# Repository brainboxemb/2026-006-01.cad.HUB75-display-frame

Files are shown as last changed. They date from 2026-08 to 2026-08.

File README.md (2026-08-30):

# HUB75 Display Frame

> The model and documentation were developed with the assistance of ChatGPT.

This repository contains the OpenSCAD development of a frame for five HUB75 LED matrix panels.

The design uses a modular OpenSCAD structure with reusable physical components, project-specific derived components and assemblies. Individual parts can be opened, rendered and tuned independently, while the complete construction can be viewed from `main.scad`.

> **Project status:** Concept development  
> V1.0 explored a frame based on 20 × 20 mm aluminium extrusion and is mainly retained as a reference concept. V1.1 explored a modular 3D-printed frame combined with two continuous aluminium tubes. Active development has moved to V1.2, which deliberately reduces the printed structure to direct panel-to-panel couplers so the mechanical strength can be tested before adding more complexity. The V1.2 couplers now use four profile modes: `large`, `medium`, `small` and `custom`; the three named presets are fixed, while `custom` activates individually editable dimensions.

## V1.0

### Inspiration

The aluminium-frame approach in V1.0 was inspired by the Instructables project [**Simple Extruded Aluminum Frame for LED Panels**](https://www.instructables.com/Simple-Extruded-Aluminum-Frame-for-LED-Panels/), created by **NotLikeALeafOnTheWind**.

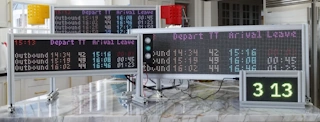
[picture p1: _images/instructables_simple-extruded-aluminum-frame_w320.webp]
Simple Extruded Aluminum Frame for LED Panels - Instructables reference (https://www.instructables.com/Simple-Extruded-Aluminum-Frame-for-LED-Panels/)


*Source: [Instructables / NotLikeALeafOnTheWind — Simple Extruded Aluminum Frame for LED Panels](https://www.instructables.com/Simple-Extruded-Aluminum-Frame-for-LED-Panels/). The image is included as a visual reference to the original project. Copyright remains with the original creator.*

### Concept

V1.0 explores an aluminium-extrusion-based structure for supporting the HUB75 panels and the components mounted directly to that structure.

The concept includes:

- a 20 × 20 mm aluminium extrusion frame;
- five HUB75 LED matrix panels;
- panel mounting brackets;
- TS35 DIN rails positioned around the panel seams;
- cable clips and ribbon-cable routing;
- frame-mounted fasteners;
- optional ESP32 mounting;
- optional power-supply mounting.

V1.0 is a concept drawing and is primarily retained as a reference for this construction approach.

The OpenSCAD model is stored in:

```text
v1.0/cad/
```

### Renders

Reference renders generated from the V1.0 OpenSCAD model are stored in:

```text
v1.0/out/png/
```

#### Front view

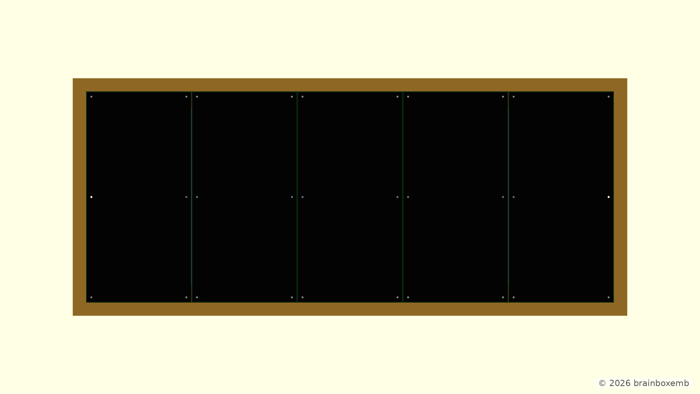
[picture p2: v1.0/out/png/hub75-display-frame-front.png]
HUB75 display frame V1.0 - front view


#### Front angled view

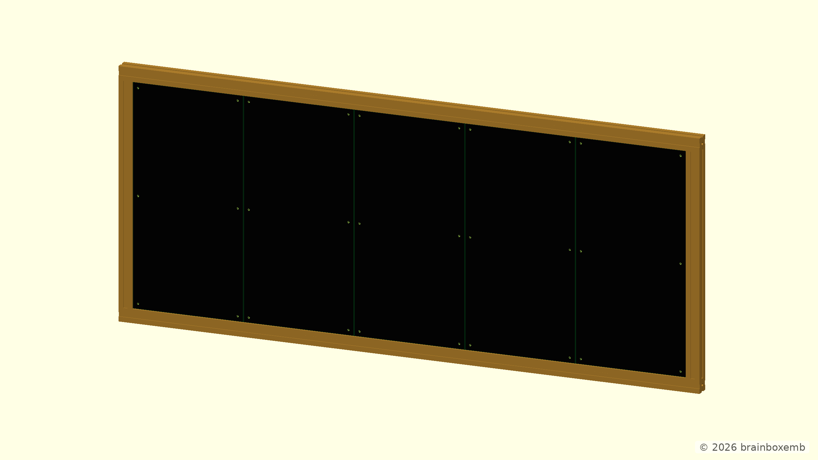
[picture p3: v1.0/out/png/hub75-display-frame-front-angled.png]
HUB75 display frame V1.0 - front angled view


#### Rear view

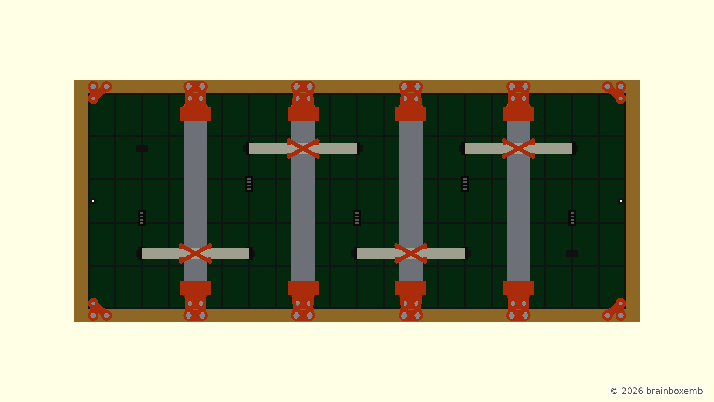
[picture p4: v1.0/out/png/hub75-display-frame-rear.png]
HUB75 display frame V1.0 - rear view


#### Rear angled view

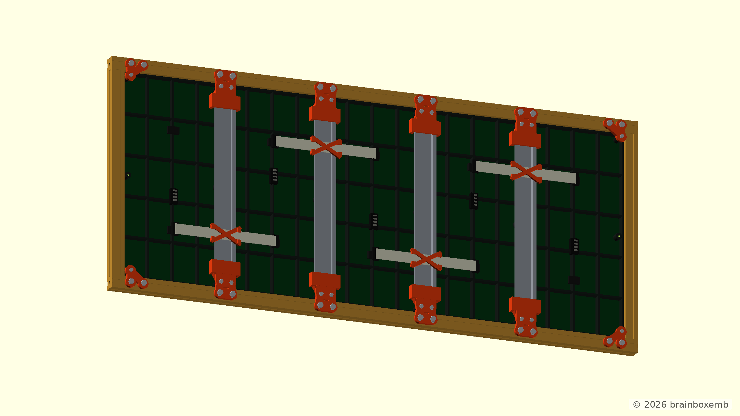
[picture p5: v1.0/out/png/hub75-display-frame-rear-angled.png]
HUB75 display frame V1.0 - rear angled view


#### Exploded rear view

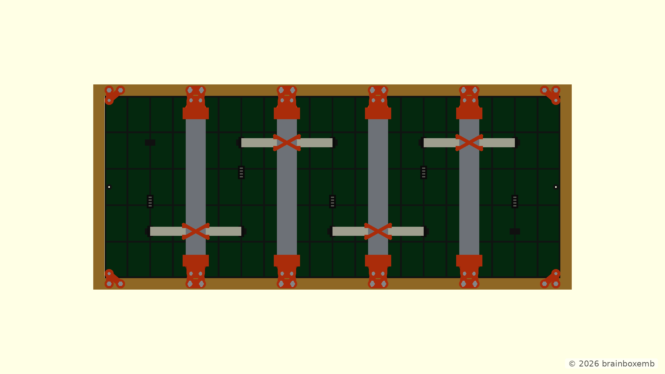
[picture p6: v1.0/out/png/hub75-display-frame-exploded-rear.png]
HUB75 display frame V1.0 - exploded rear view


#### Exploded rear angled view

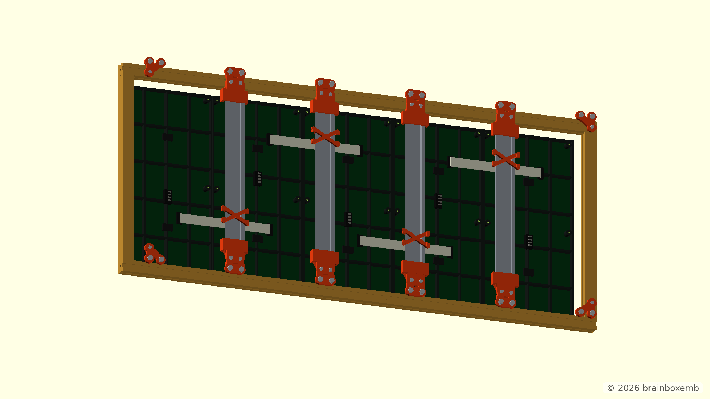
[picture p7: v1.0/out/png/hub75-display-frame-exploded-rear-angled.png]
HUB75 display frame V1.0 - exploded rear angled view


### CAD structure

The V1.0 OpenSCAD model is divided into configuration, individual components and assemblies. Fixed render definitions are included so documentation images can be reproduced locally or by the shared GitHub Actions renderer.

```text
v1.0/cad/
├── main.scad
├── config/
│   └── project_config.scad
├── components/
│   ├── ...
│   └── _lib/
│       └── fasteners.scad
├── assemblies/
│   ├── display_assembly.scad
│   ├── frame_assembly.scad
│   ├── panels_assembly.scad
│   ├── hardware_assembly.scad
│   ├── frame_system_assembly.scad
│   └── ...
└── renders/
    ├── front.scad
    ├── front_angled.scad
    ├── rear.scad
    ├── rear_angled.scad
    ├── exploded_rear.scad
    └── exploded_rear_angled.scad
```

Open `v1.0/cad/main.scad` to view and configure the complete model.

## V1.1

### Inspiration

The modular frame approach explored in V1.1 was partly inspired by a **modular MFT router jig**. Its use of repeatable 3D-printed sections that combine into a larger structure helped shape the idea of building the HUB75 support frame from a regular grid of printed modules.

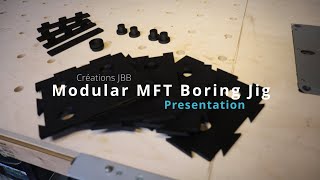
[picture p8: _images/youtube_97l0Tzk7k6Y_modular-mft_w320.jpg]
Modular MFT concept - YouTube reference (https://www.youtube.com/watch?v=97l0Tzk7k6Y)


*Source: [YouTube — Modular MFT reference](https://www.youtube.com/watch?v=97l0Tzk7k6Y). The image is included as a visual reference to the original video. Copyright remains with the original creator.*

The MFT concept was used as inspiration for the **modular construction principle and overall module shape**. V1.1 adapts that idea to the mechanical requirements and mounting pattern of the HUB75 display panels.

### Concept

V1.1 takes a different approach to the structural frame.

Instead of using 20 × 20 mm aluminium extrusion as the main structure, the frame is built from modular **160 × 160 mm 3D-printed sections**. The module size follows the nominal 160 mm dimension of the HUB75 panels and creates a regular 5 × 2 structural grid behind the five displays.

The current concept includes:

- ten 160 × 160 mm 3D-printed frame modules;
- large central openings to reduce material usage and keep the rear of the panels accessible;
- interlocking edges that position neighbouring frame modules;
- alternating module colours in the OpenSCAD model to make the modular construction easier to inspect;
- mounting features that use the existing HUB75 panel screw locations;
- dedicated seam joiners connecting neighbouring panels and frame sections;
- two continuous Ø10 × 1 mm aluminium tubes, each 800 mm long;
- integrated snap clamps connecting the upper and lower frame modules to these tubes.

The aluminium tubes provide a continuous structural reference across the full width of the display and are intended to improve alignment and stiffness.

Their position also leaves open the possibility of using the tubes as a mounting interface for additional parts on the front side, such as a future display surround or bezel.

V1.1 is retained as the more elaborate modular printed-frame concept. V1.2 intentionally simplifies this approach before further refinement.

The OpenSCAD model is stored in:

```text
v1.1/cad/
```

### Renders

Reference renders generated from the current V1.1 OpenSCAD model are stored in:

```text
v1.1/out/png/
```

#### Front view

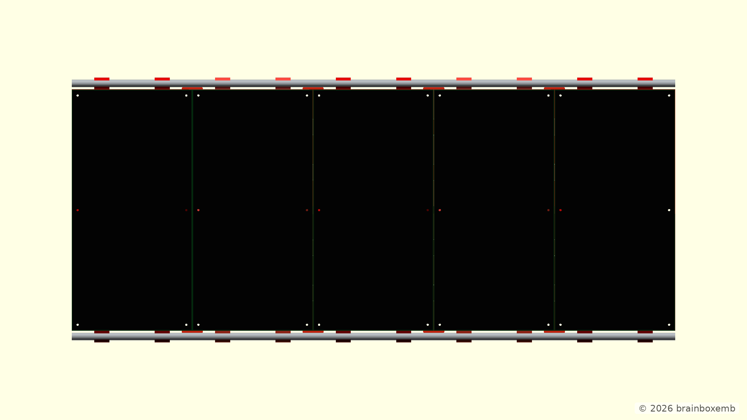
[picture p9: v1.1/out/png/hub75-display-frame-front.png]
HUB75 display frame V1.1 - front view


#### Front angled view

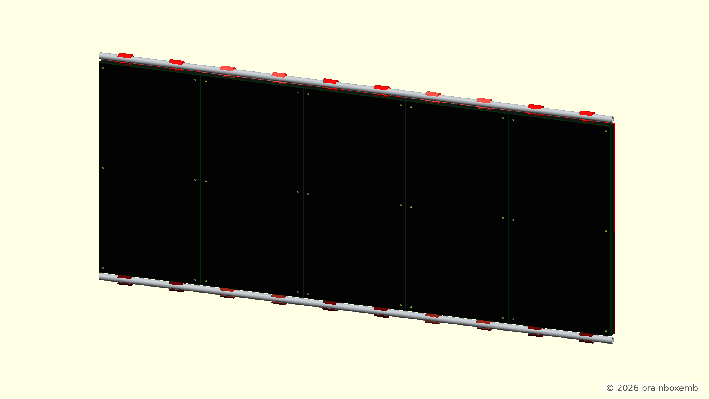
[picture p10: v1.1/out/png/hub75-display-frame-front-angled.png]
HUB75 display frame V1.1 - front angled view


#### Rear view

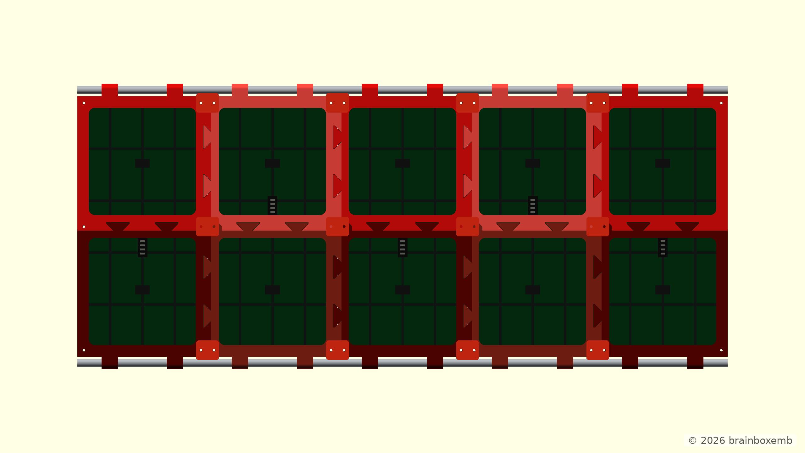
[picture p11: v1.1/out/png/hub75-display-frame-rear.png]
HUB75 display frame V1.1 - rear view


#### Rear angled view

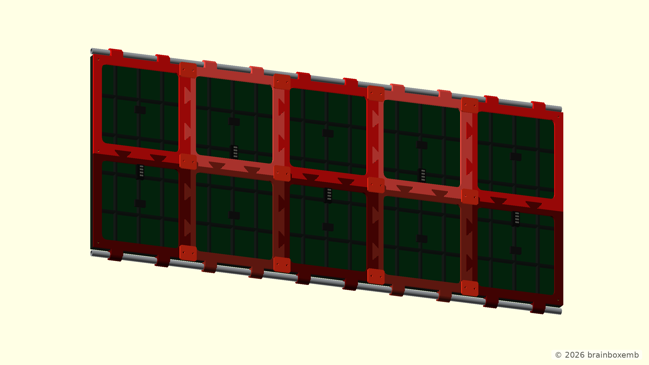
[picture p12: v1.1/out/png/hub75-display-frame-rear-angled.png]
HUB75 display frame V1.1 - rear angled view


#### Exploded rear view

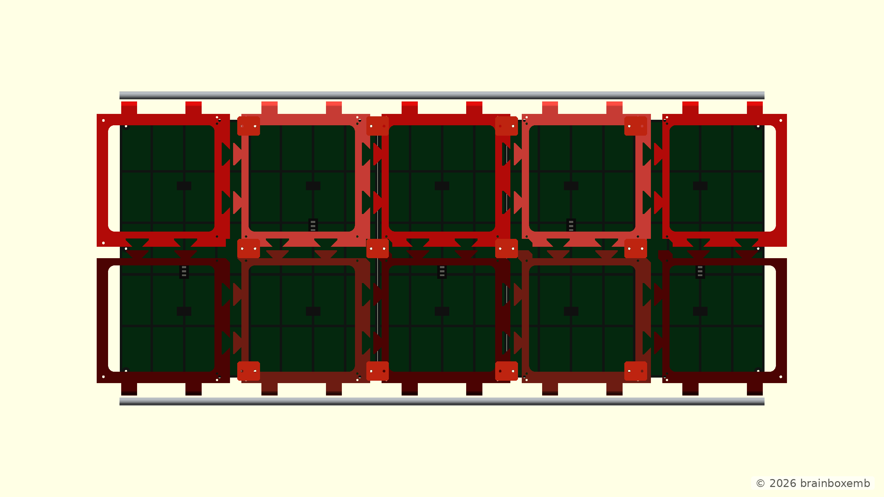
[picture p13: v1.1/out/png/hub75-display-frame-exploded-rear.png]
HUB75 display frame V1.1 - exploded rear view


#### Exploded rear angled view

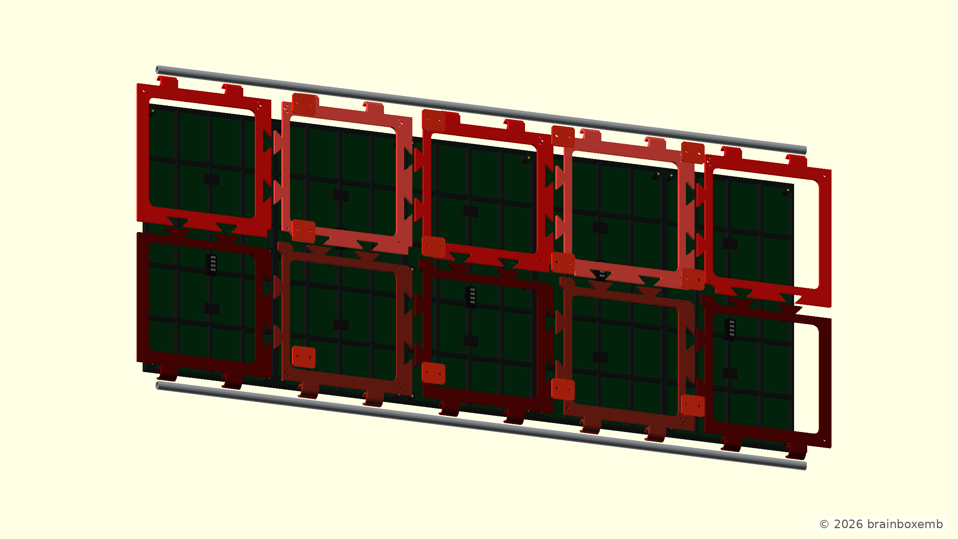
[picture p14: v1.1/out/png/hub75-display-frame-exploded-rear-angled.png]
HUB75 display frame V1.1 - exploded rear angled view


### CAD structure

V1.1 continues to use the modular OpenSCAD structure introduced for the project.

```text
v1.1/cad/
├── main.scad
├── config/
│   └── project_config.scad
├── components/
│   ├── hub75_panel.scad
│   ├── frame_module.scad
│   ├── panel_seam_joiner.scad
│   └── ...
├── assemblies/
│   ├── panels_assembly.scad
│   ├── frame_modules_assembly.scad
│   ├── seam_joiners_assembly.scad
│   ├── display_assembly.scad
│   └── ...
└── renders/
    ├── front.scad
    ├── front_angled.scad
    ├── rear.scad
    ├── rear_angled.scad
    ├── exploded_rear.scad
    └── exploded_rear_angled.scad
```

Open `v1.1/cad/main.scad` to view the complete concept.

## V1.2

V1.2 coupler placement is based on the exact 160 × 320 mm nominal panel grid. Local seam locators use the larger gap at the tapered rear mounting plane, with 0.25 mm print clearance per side; see `v1.2/doc/grid-and-fit.md`.

### Concept

V1.2 is a deliberately simpler continuation of V1.1.

Instead of building a complete 160 × 160 mm printed frame grid first, V1.2 connects the HUB75 panels directly at their existing screw positions. The purpose of this version is to manufacture and test the simplest useful structure and determine how much stiffness the direct panel connections and aluminium tubes already provide.

The current V1.2 concept includes:

- five HUB75 panels in the same nominal 800 × 320 mm arrangement;
- no 160 × 160 mm printed frame modules;
- no puzzle or dovetail interlocks;
- four `middle_panel_coupler` parts at the internal panel seams;
- upper and lower `horizontal_edge_panel_coupler` parts at each internal seam;
- separate mirrored `corner_edge_panel_coupler` variants at the four outside corners;
- two continuous Ø10 × 1 mm aluminium tubes;
- dedicated fit-section views for checking the coupler-to-panel interfaces.

The printed couplers follow the actual rear-panel rib geometry and use the existing screw locations, locator features and reinforcement-bushing geometry as alignment references. The edge and corner families are dimensioned from the nominal 160 × 320 mm panel boundary while their physical fit geometry remains tied to the real panel rails, holes and bosses. This keeps the parts visually and mechanically consistent without moving the real fit features.

The nominal placement grid is authoritative: the original panel is **320 × 160 mm**, and in this portrait assembly each cell is therefore **160 mm in X × 320 mm in Z**. The measured physical panel is 159.70 × 319.71 mm and is centred inside that cell. Internal coupler centres sit exactly on the nominal grid boundaries, while the physical undersize appears only as a small panel-to-panel gap. Panel-fit guides use a fixed **0.25 mm clearance per mating side**, independent of the small/medium/large coupler profile. The seam locator does not use the 0.30 mm front/body gap: it engages at the tapered rear mounting plane, where the usable seam is wider. With the STEP-derived rear inset and 0.25 mm print clearance per mating side, the current locator is about 2.30 mm wide and remains centred exactly on the nominal grid seam. The same mounting-plane rule is now used for the guide keep-outs themselves: because the outer housing tapers inward while the bay openings remain vertical, the effective side/end rails at the rear face are smaller than the nominal 12.5/10.75 mm reference widths. Middle, horizontal-edge and corner guides therefore all use the same rear-plane rail dimensions before adding the fixed 0.25 mm clearance.

### Panel dimensional basis

For V1.2, the panel's mechanical dimensions and mounting pattern are modelled in `components/hub75_panel.scad`. This component is deliberately project-independent and is the authoritative source for the physical panel geometry.

Current principal dimensions are:

```text
Panel width       159.70 mm
Panel height      319.71 mm
Panel depth        14.50 mm
```

The panel component also owns the rear rib geometry, mounting-hole pattern, IDC connector geometry, locator pins and reinforcement-bushing dimensions. The reinforcement feature is modelled as a Ø14 mm internal boss that is flush with the rear mounting plane, with a Ø10 mm × 2.5 mm recess and a central Ø2.5 mm blind hole extending 10 mm from the bottom of that recess.

### Aluminium tube layout

V1.2 now defines the aluminium-tube placement as an explicit **project-level relationship**, rather than deriving it indirectly from the clip geometry.

The current reference envelope is:

```text
Overall project envelope       840 × 360 mm
Tube centre-to-centre spacing  340 mm
Tube outer diameter             10 mm
Tube centre from panel rear      7 mm
```

The 840 × 360 mm project envelope is centred around **X = 0 / Z = 0**. The project assembly uses the **rear mounting plane of the HUB75 panels as Y = 0**. The two tube centres are positioned symmetrically at Z = ±170 mm, giving a 340 mm centre-to-centre distance. Their Y centre is **-7 mm**, i.e. 7 mm from the rear mounting plane toward the panel front.

`main.scad` also provides an optional `show_project_envelope` checkbox. When enabled, a wireframe 840 × 360 mm reference box is drawn around the assembly. Its Y-direction corner lines extend from the panel front face to the Y=0 rear mounting plane, making the panel depth and the project Y reference easy to inspect.

The Y position is defined from the **rear mounting plane of the HUB75 panel toward the front face**. With the rear plane at Y=0, the 14.5 mm panel front is at Y=-14.5 mm and the Ø10 mm tube centre is at Y=-7 mm. This leaves:

- 2.0 mm between the rear panel plane and the nearest tube surface;
- 2.5 mm between the opposite tube surface and the panel front face.

This relationship is stored in `config/project_config.scad` as:

```scad
display_envelope_width = 840.0;
display_envelope_height = 360.0;
tube_center_spacing = 340.0;
tube_center_from_panel_rear = 7.0;
```

The physical tube dimensions remain in `components/aluminium_tube.scad`.

### Configuration architecture

V1.2 deliberately separates **reusable physical components** from **project-derived printable parts**.

`components/` contains parts whose physical definition is independent of this specific five-panel assembly. Examples include:

- `hub75_panel.scad` — authoritative HUB75 panel geometry;
- `aluminium_tube.scad` — physical tube diameter and wall thickness;
- `tube_clip.scad` — reusable snap-clip geometry;
- `_lib/reference_grid.scad` — generic inspection helper.

`project_components/` contains printable parts whose geometry is deliberately derived from both reusable component dimensions and `project_config.scad`. The V1.2 couplers belong here because their clip positions, display-edge relationships and assembly clearances are specific to this project configuration. Shared coupler rules such as rail-following fit and profile dimensions are kept in `project_components/_lib/` so edge and corner variants do not duplicate those calculations. The material wall and guide height are selected through the project-wide coupler design profile.

This means it is expected and intentional that a file in `project_components/` can depend on project settings. A generic component under `components/` should not.

### Panel chain order

Panel order is defined **from the rear of the display**. By default, **panel 1 is the rear-left panel and its HUB75 input is at the top**. Every following panel is rotated 180 degrees so the data path snakes across the rear of the display.

The start side and the first input position are explicit project parameters:

```text
rear_chain_start_side = "left"
first_panel_input_side = "top"
```

### Bracket inspiration

The following Printables projects are useful references for refining the printed panel couplers and brackets.

#### Brackets for joining HUB75 LED panels

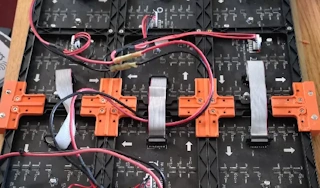
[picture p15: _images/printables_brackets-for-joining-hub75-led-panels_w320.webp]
Brackets for joining HUB75 LED panels (https://www.printables.com/model/1294572-brackets-for-joining-hub75-led-panels)


*Source: [Printables — Brackets for joining HUB75 LED panels](https://www.printables.com/model/1294572-brackets-for-joining-hub75-led-panels).*

#### HUB75 5mm Pitch 4 Panel Bracket

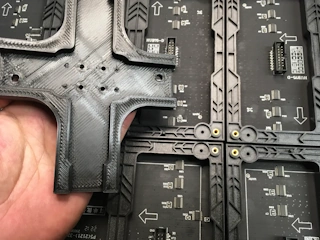
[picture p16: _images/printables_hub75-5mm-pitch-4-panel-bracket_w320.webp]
HUB75 5mm Pitch 4 Panel Bracket (https://www.printables.com/model/578204-hub75-5mm-pitch-4-panel-bracket)


*Source: [Printables — HUB75 5mm Pitch 4 Panel Bracket](https://www.printables.com/model/578204-hub75-5mm-pitch-4-panel-bracket).*

### Renders

Reference renders generated from the current V1.2 OpenSCAD model are stored in:

```text
v1.2/out/png/
```

#### Panel reference

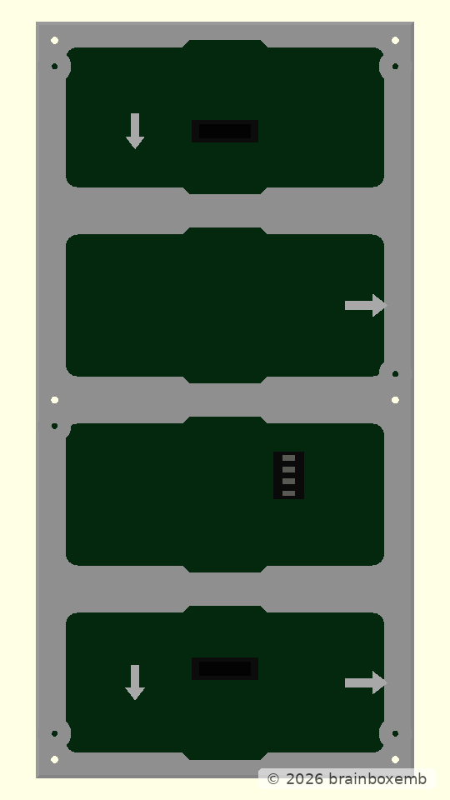
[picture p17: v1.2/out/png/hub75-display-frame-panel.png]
HUB75 panel V1.2 - rear reference


#### Panel reference — angled

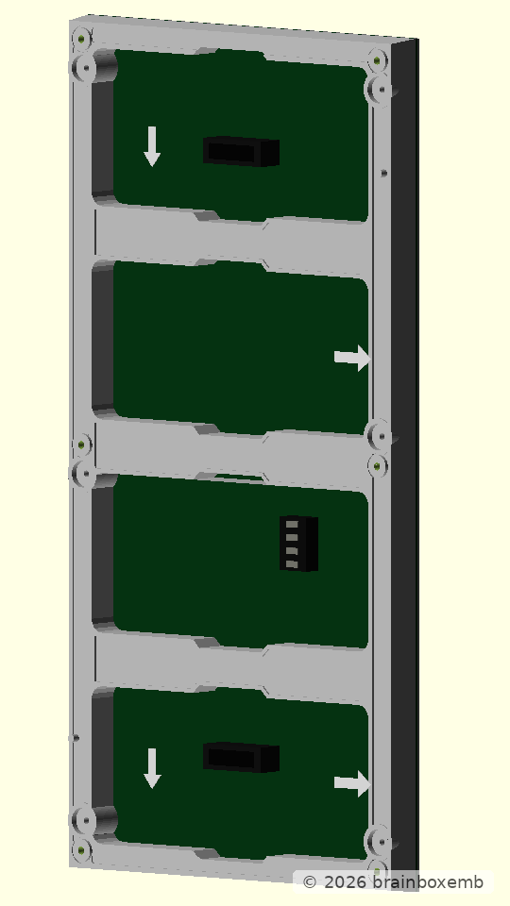
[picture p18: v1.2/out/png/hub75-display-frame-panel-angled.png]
HUB75 panel V1.2 - angled rear reference


#### Front view

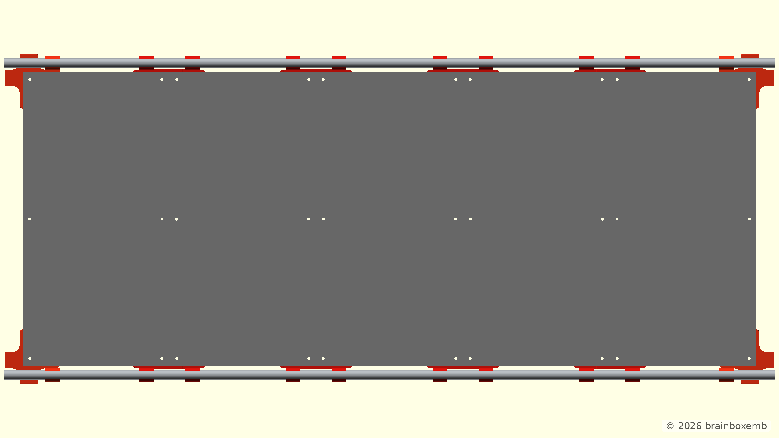
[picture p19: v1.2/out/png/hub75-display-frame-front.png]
HUB75 display frame V1.2 - front view


#### Front angled view

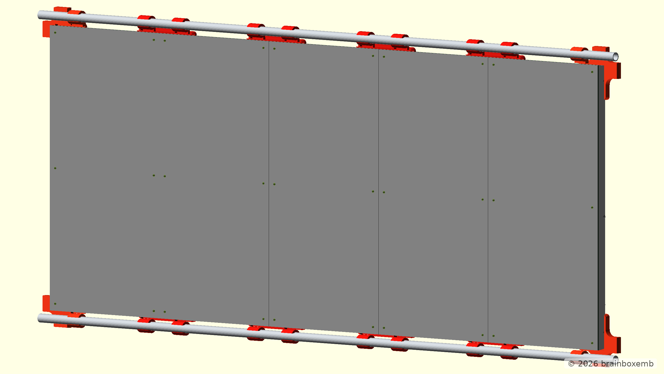
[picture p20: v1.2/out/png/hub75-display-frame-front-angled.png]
HUB75 display frame V1.2 - front angled view


#### Rear view

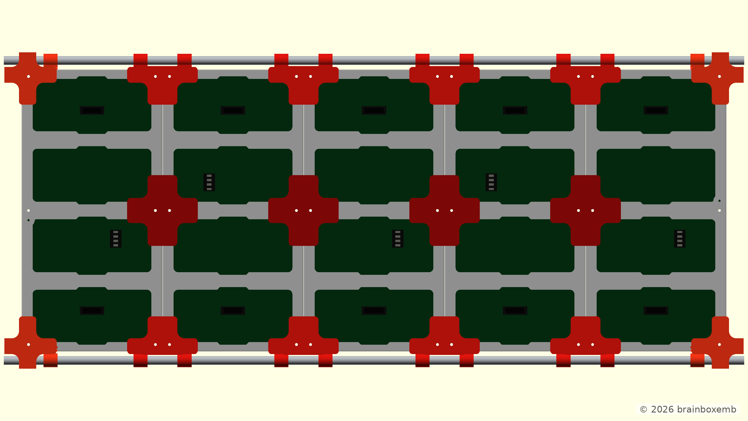
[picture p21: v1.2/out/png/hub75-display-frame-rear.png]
HUB75 display frame V1.2 - rear view


#### Rear angled view

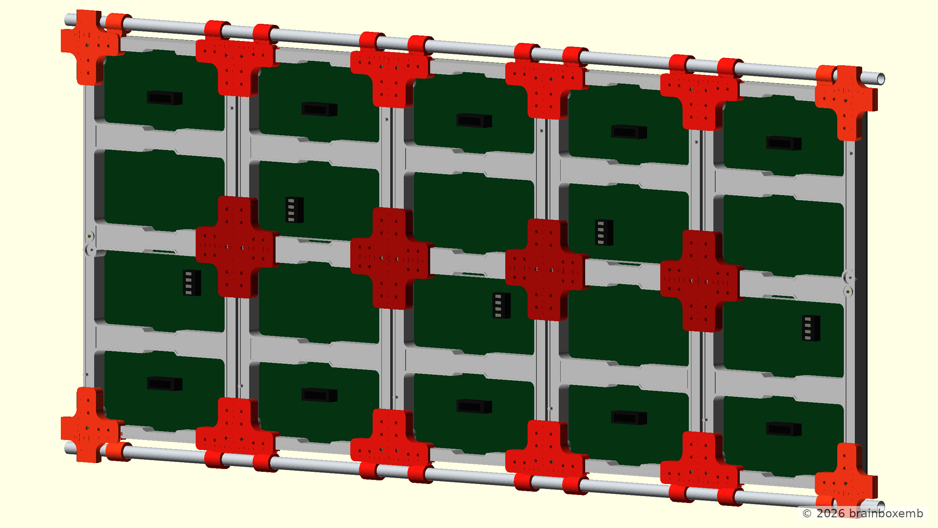
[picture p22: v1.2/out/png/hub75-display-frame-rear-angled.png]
HUB75 display frame V1.2 - rear angled view


#### Rear wiring / panel order

This view shows the HUB75 panel chain as seen from the rear. Panel 1 is the first module in the chain, with its input positioned at the top. The alternating panel orientation makes the intended IN/OUT routing across the five panels easier to verify.

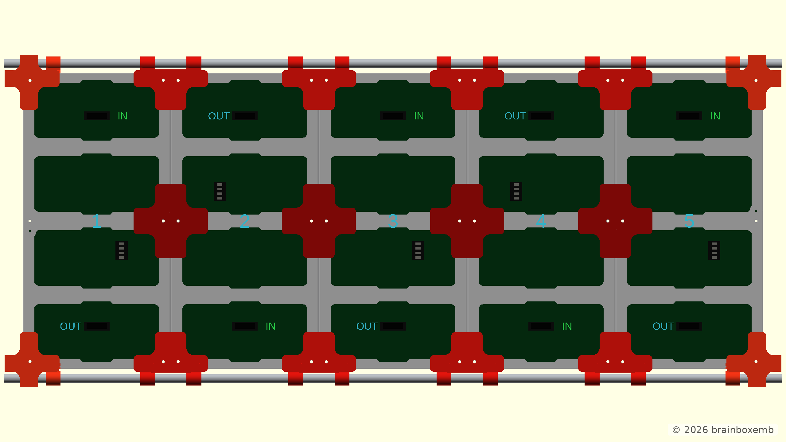
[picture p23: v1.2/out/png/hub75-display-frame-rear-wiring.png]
HUB75 display frame V1.2 - rear wiring and panel order


#### Rear fit section

This diagnostic render shows a section through the complete rear assembly, 5 mm into the panel structure. It is intended to make the fit between the printed couplers and the HUB75 rear ribs visible across all panel seams at once.

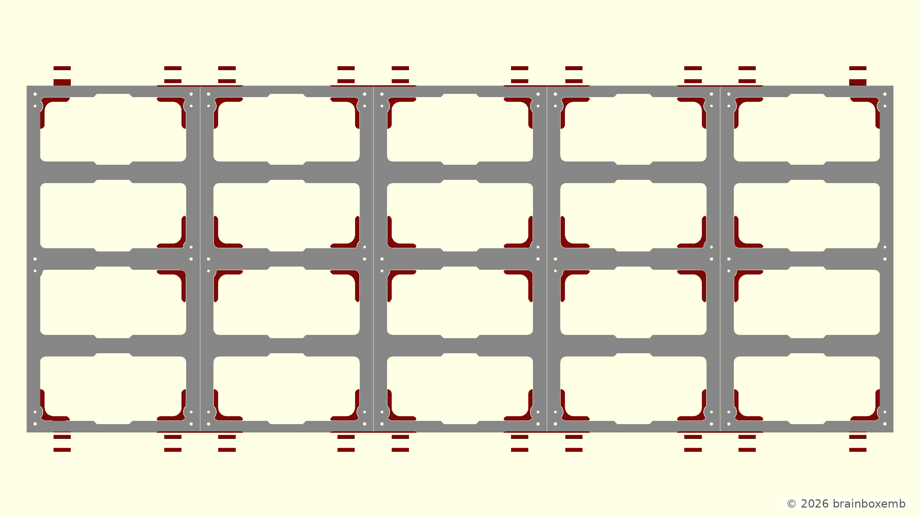
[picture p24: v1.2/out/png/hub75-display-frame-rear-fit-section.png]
HUB75 display frame V1.2 - rear fit section


#### Coupler comparison — side by side

All four printable coupler variants are shown next to each other using their
geometric `+` reference points rather than their screw holes as the alignment
reference. The reference points are placed on grid intersections, making it
easier to compare the nominal panel-edge references, overall height and profile
proportions across the coupler family.

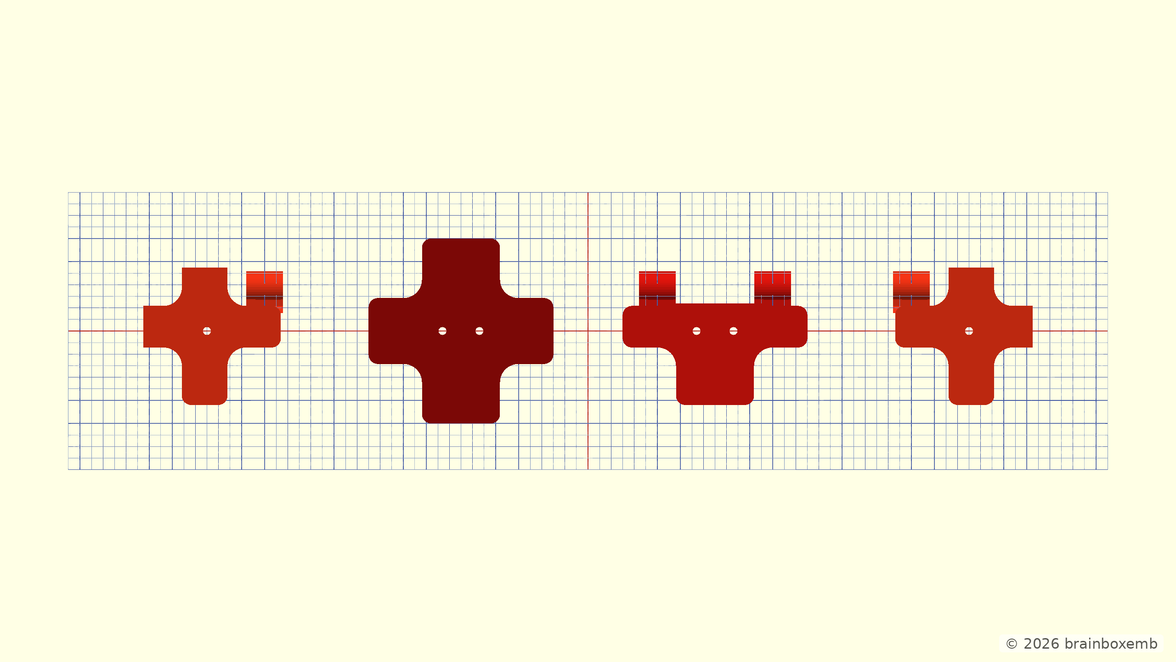
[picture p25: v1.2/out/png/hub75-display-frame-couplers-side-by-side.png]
HUB75 display frame V1.2 - couplers side by side


#### Coupler comparison — stacked

The two coupler comparison renders use the standard reference grid by default (10 mm major spacing with 5 mm half-steps), while the same grid remains controlled by `show_reference_grid` in `main.scad`.

The same four variants are stacked vertically for a second proportional check.
The view is intended primarily for comparing overall width and the relationship
between the shared profile rules of the middle, edge and corner variants.

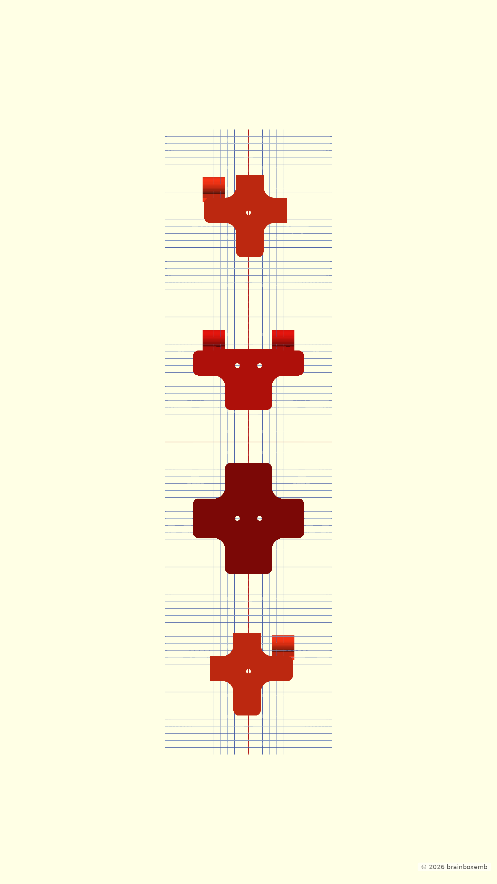
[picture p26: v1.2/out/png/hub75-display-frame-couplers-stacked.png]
HUB75 display frame V1.2 - couplers stacked


#### XY coupler fit cross-sections

Two additional diagnostic renders are true **XY-plane slices at a fixed Z height**. The slice is placed just inboard of the horizontal coupler arm, so the arm cannot hide the fit. Looking perpendicular to the XY plane shows the physical panel edges, rear seam gap, locator rib and guide geometry in depth. This is the intended check for left/right print clearance and centring on the nominal seam. Both use the canonical `medium` profile.

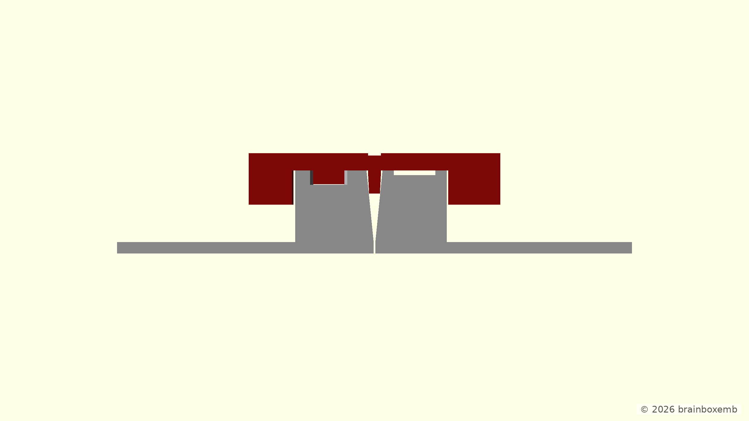
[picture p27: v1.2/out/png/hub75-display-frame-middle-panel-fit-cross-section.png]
HUB75 display frame V1.2 - middle XY fit cross-section


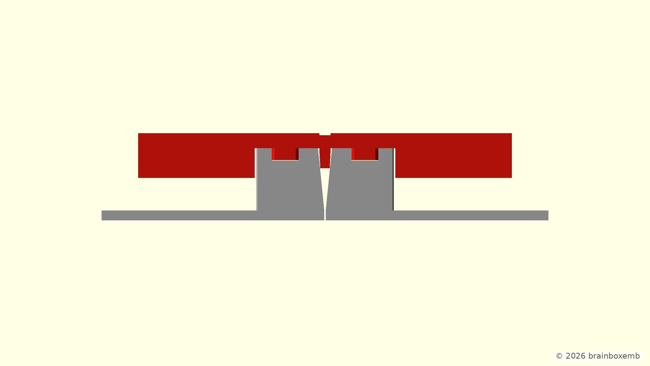
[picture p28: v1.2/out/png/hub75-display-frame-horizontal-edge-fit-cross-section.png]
HUB75 display frame V1.2 - horizontal edge XY fit cross-section


#### Exploded rear view

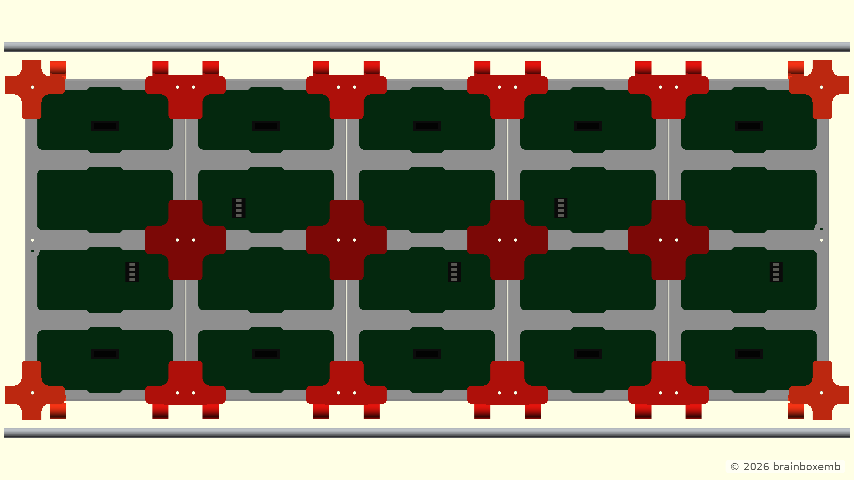
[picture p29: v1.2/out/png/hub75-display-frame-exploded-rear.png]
HUB75 display frame V1.2 - exploded rear view


#### Exploded rear angled view

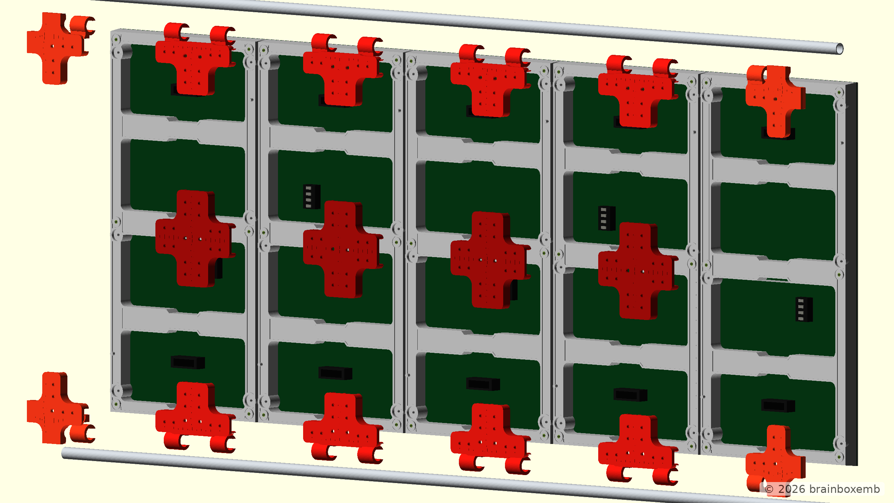
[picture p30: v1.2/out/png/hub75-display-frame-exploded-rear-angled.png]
HUB75 display frame V1.2 - exploded rear angled view


### Coupler design profiles

V1.2 provides three fixed project-wide coupler presets plus a custom mode. The profile can be selected from the OpenSCAD Customizer when `v1.2/cad/main.scad` is open.

| Profile | Envelope | Wall | Guide height | Base | Corner radius | Edge radius | Tube clip offset |
|---|---:|---:|---:|---:|---:|---:|---:|
| Small | 60 × 60 mm | 2 mm | 4 mm | 2 mm | 6 mm | 3 mm | 18 mm |
| Medium | 80 × 80 mm | 4 mm | 6 mm | 3 mm | 8 mm | 4 mm | 25 mm |
| Large | 100 × 100 mm | 6 mm | 10 mm | 4 mm | 10 mm | 5 mm | 25 mm |

The three named presets are fixed and reproducible. **Medium is the canonical V1.2 profile** and is used by the normal full-display documentation renders and the complete display STL. The numeric fields under **Custom coupler dimensions** are ignored while `large`, `medium` or `small` is selected. Selecting `custom` activates the same seven design settings shown in the table above. The custom fields start with the medium values as a practical baseline.

`corner_radius`, `edge_radius` and `tube_clip_offset` are explicit profile/custom settings. **Guide length is not a setting.** Guide transition and maximum reach are derived from the selected profile values: the guide runs to the start of the plate edge radius, follows the edge for 30% of the guide-wall width, and uses the remaining 70% of the guide-wall width for its own end-cap depth.

The decorative Ø3 mm blind-pocket raster adapts automatically to the effective profile size. Individual printable couplers are rendered and exported as STL for all three named profiles. Reusable objects such as the HUB75 panel and aluminium tube remain independent of these project-specific choices.

#### Profile render galleries

Each profile has a single Markdown gallery so all of its coupler renders can be reviewed without opening the PNG files one by one:

- [Small coupler profile](v1.2/doc/small.md)
- [Medium coupler profile](v1.2/doc/medium.md) — canonical V1.2 profile
- [Large coupler profile](v1.2/doc/large.md)

### CAD structure

```text
v1.2/cad/
├── main.scad
├── config/
│   └── project_config.scad
├── components/
│   ├── hub75_panel.scad
│   ├── aluminium_tube.scad
│   ├── tube_clip.scad
│   └── _lib/
│       ├── reference_grid.scad
│       └── reference_box.scad
├── project_components/
│   ├── middle_panel_coupler.scad
│   ├── horizontal_edge_panel_coupler.scad
│   ├── corner_edge_panel_coupler.scad
│   └── _lib/
│       ├── coupler_profile.scad
│       └── coupler_dimensions.scad
├── assemblies/
│   ├── panels_assembly.scad
│   ├── couplers_assembly.scad
│   ├── tubes_assembly.scad
│   ├── coupler_fit_cross_sections.scad
│   ├── rear_fit_section.scad
│   ├── coupler_comparison_assembly.scad
│   └── display_assembly.scad
├── exports/
│   ├── display.scad                         # canonical MEDIUM complete display
│   ├── middle_panel_coupler_{small,medium,large}.scad
│   ├── horizontal_edge_panel_coupler_{small,medium,large}.scad
│   ├── corner_edge_panel_coupler_left_{small,medium,large}.scad
│   └── corner_edge_panel_coupler_right_{small,medium,large}.scad
└── renders/
    ├── front.scad
    ├── front_angled.scad
    ├── panel.scad
    ├── panel_angled.scad
    ├── rear.scad
    ├── rear_angled.scad
    ├── rear_wiring.scad
    ├── middle_panel_fit_cross_section.scad
    ├── horizontal_edge_fit_cross_section.scad
    ├── rear_fit_section.scad
    ├── couplers_side_by_side.scad          # canonical MEDIUM comparison
    ├── couplers_stacked.scad                # canonical MEDIUM comparison
    ├── couplers_{small,medium,large}_side_by_side.scad
    ├── couplers_{small,medium,large}_stacked.scad
    ├── couplers_{small,medium,large}_middle.scad
    ├── couplers_{small,medium,large}_horizontal_edge.scad
    ├── couplers_{small,medium,large}_corner_left.scad
    ├── couplers_{small,medium,large}_corner_right.scad
    ├── exploded_rear.scad
    └── exploded_rear_angled.scad
```

Open `v1.2/cad/main.scad` to view the complete concept.

`assemblies/coupler_comparison_assembly.scad` is also directly openable in OpenSCAD. It provides `side_by_side` and `stacked` comparison modes and can use the same reference-grid settings as the normal inspection views.

## Automatic renders and exports

The official PNG views and printable STL exports are generated through the shared reusable workflow in the `brainboxemb/brainboxemb.github.actions` repository.

The HUB75 repository keeps the small caller workflow:

```text
.github/workflows/render-openscad.yml
```

Each CAD version keeps its fixed camera definitions in `renders/*.scad`. For V1.2 the normal display renders are fixed to the canonical `medium` profile. Additional coupler-only render entry points generate `small`, `medium` and `large` comparison/detail images. V1.2 also keeps printable entry points in `exports/*.scad`: the complete assembled display is exported once in `medium`, while each individual coupler variant is exported separately for `small`, `medium` and `large`.

Generated render output is stored under:

```text
v1.0/out/png/
v1.1/out/png/
v1.2/out/png/
```

## Repository structure

```text
.
├── README.md
├── _images/
│   ├── instructables_simple-extruded-aluminum-frame_w320.webp
│   ├── youtube_97l0Tzk7k6Y_modular-mft_w320.jpg
│   ├── printables_brackets-for-joining-hub75-led-panels_w320.webp
│   └── printables_hub75-5mm-pitch-4-panel-bracket_w320.webp
├── doc/
│   ├── v1.0/
│   ├── v1.1/
│   └── v1.2/
│       ├── README.md
│       ├── small.md
│       ├── medium.md
│       └── large.md
├── .github/
│   └── workflows/
│       └── render-openscad.yml
├── cad/
│   ├── v1.0/
│   ├── v1.1/
│   └── v1.2/
└── out/
    ├── v1.0/
    ├── v1.1/
    └── v1.2/
```

### V1.2 fit verification

The rear-fit diagnostic render hides the panel front face/PCB and shows only the rear structural rims, making panel seams and coupler engagement easier to inspect.

### Guide reach and rounded arm ends

The guide free end uses one shared construction rule for middle, horizontal-edge and corner couplers. At the start of the plate `edge radius`, 30% of the guide wall width continues along the plate curve. The remaining 70% defines the guide's own end radius. This keeps the transition tied to the actual guide width rather than to a profile-size percentage or a fixed per-profile dimension.

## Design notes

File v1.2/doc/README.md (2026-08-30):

# V1.2 coupler profile renders

> The model and documentation were developed with the assistance of ChatGPT.

V1.2 uses **medium** as the canonical/default profile for the complete display renders and complete display STL.

| Profile | Envelope | Wall | Guide | Base |
| --- | ---: | ---: | ---: | ---: |
| [Small](small.md) | 60 × 60 mm | 2 mm | 4 mm | 2 mm |
| [Medium](medium.md) | 80 × 80 mm | 4 mm | 6 mm | 3 mm |
| [Large](large.md) | 100 × 100 mm | 6 mm | 10 mm | 4 mm |

Each profile page embeds all coupler renders directly, so the images can be reviewed without opening the generated PNG files one by one.
## Grid and panel fit

All V1.2 couplers are positioned from the exact nominal panel grid. The supplied 320 × 160 mm panel is used portrait, so the assembly grid is 160 mm in X by 320 mm in Z. The measured 159.70 × 319.71 mm body is centred inside that cell. Rear-rail guides use 0.25 mm print clearance per mating side; the 0.30 mm inter-panel gap is too small for a printable seam blade, so no artificial 3 mm wedge is generated.

## Design contract

- [Coupler design requirements](coupler-design-requirements.md)

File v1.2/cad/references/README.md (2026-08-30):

# V1.2 coordinate reference drawings

These standalone OpenSCAD files are the coordinate/fit verification layer between the physical HUB75 panel model and the printable couplers.

Every panel is defined once around its own local `(0,0)`. Component drawings only translate that canonical panel into the component-local coordinate system.

## Boundary layers

Each drawing can show four distinct panel boundaries:

1. **Nominal grid** — exact 160 × 320 mm portrait placement cell (320 × 160 mm landscape).
2. **Physical front outer** — measured physical panel envelope.
3. **Rear outer** — outside edge at the rear mounting plane after the housing taper.
4. **Rear inner edge** — inside boundary of the outer rear side/end rails. This is the critical second boundary for coupler fit.

Mounting-hole centres are shown from the same canonical panel coordinate model.

## Standalone drawings

- `panel_reference.scad` — one panel around panel-local `(0,0)`.
- `middle_reference.scad` — two adjacent panels; middle bridge origin on their nominal seam.
- `horizontal_edge_reference.scad` — two adjacent panels; origin where the nominal seam meets the nominal top edge.
- `corner_left_reference.scad` — top-left nominal panel corner at component `(0,0)`.
- `corner_right_reference.scad` — top-right nominal panel corner at component `(0,0)`.

Bottom edge/corner placement is the mirrored form of the top references.

## Grid

All files are standalone Customizer entrypoints. They reuse the **same shared grid implementation** as the normal top-level CAD inspection views (`components/_lib/reference_grid.scad`).

Each reference file exposes:

```scad
show_grid = true;
grid_major = 10;
grid_show_half = true;
```

so the grid can be enabled/disabled even when opening only a file from this directory.

## Geometry source

The reference drawings use the same `components/_lib/panel_fit_geometry.scad`
adapter as the printable couplers. This is intentional: a line shown in a
reference drawing and the matching coupler keep-out are derived from the same
panel geometry instead of copied dimensions.

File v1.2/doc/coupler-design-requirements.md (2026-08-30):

# V1.2 coupler design requirements

This document is the design contract for the printable HUB75 coupler family.
The OpenSCAD implementation should be checked against these rules before local
geometry is adjusted.

## 1. Authoritative panel geometry

`components/hub75_panel.scad` is the authoritative source for the physical HUB75
panel. Couplers must not copy panel dimensions or reconstruct the same panel
edge independently.

All coupler fit geometry is derived through the shared panel-fit layer:

- nominal 160 × 320 mm portrait placement grid;
- physical front outer contour;
- physical rear outer contour;
- physical rear inner/opening contour;
- mounting-hole and locator positions.

The nominal grid determines placement. The physical rear geometry determines
fit. Those two coordinate systems must never be substituted for each other.

## 2. One shared coupler profile system

The named profiles explicitly define the same design settings that are exposed
when `custom` is selected. This keeps fixed presets and custom mode conceptually
consistent.

| Profile | Size | Wall | Guide height | Base | Corner radius | Edge radius | Tube clip offset |
|---|---:|---:|---:|---:|---:|---:|---:|
| Small | 60 mm | 2 mm | 4 mm | 2 mm | 6 mm | 3 mm | 18 mm |
| Medium | 80 mm | 4 mm | 6 mm | 3 mm | 8 mm | 4 mm | 25 mm |
| Large | 100 mm | 6 mm | 10 mm | 4 mm | 10 mm | 5 mm | 25 mm |

These are **profile settings**. Derived geometry such as the start of the plate
edge radius, guide transition, plate-follow depth, cap depth and maximum guide
reach must be calculated from these settings. They are not extra Customizer
controls and must not be stored as a second set of small/medium/large constants
in individual component files.

## 3. Plate shape

The plate has two visually different radii:

- `corner_radius`: concave transition from an arm into the central body;
- `edge_radius`: convex radius at the free end of an arm.

The plate must remain large enough to support the complete fitted guide. A guide
must never hang outside its supporting plate because the source envelope was
cropped too early.

## 4. Guide fit

The guide is derived from the actual rear panel keep-out plus the configured
print clearance. It is not independently positioned from the plate.

The same physical rear edge must produce the same fit clearance in middle,
horizontal-edge and corner couplers.

## 5. Guide free-end shape

The guide must never end in a square cut or a sharp kink.

At a free plate end the construction is:

1. the straight guide continues to the start of the plate `edge_radius`;
2. it follows the plate curve for **30% of the guide-wall width**;
3. from that transition point the remaining **70% of the guide-wall width** is
   used as the axial depth of the guide's own smooth rounded cap;
4. the own cap joins the straight/following guide tangentially;
5. the complete result is intersected with the authoritative fitted shell, so
   the end-shaping operation can remove material but can never add material
   outside the plate or into the panel keep-out.

The shared rounded-end split is based on **guide-wall width**. It is not a percentage of
profile size and not a percentage of plate radius.

## 6. Guide length

`guide_length` is an outcome, not an independent percentage of profile size.

The important derived locations are:

- start of the plate edge radius: `profile_size / 2 - edge_radius`;
- plate-follow depth: `guide_wall × 0.30`;
- guide-cap depth: `guide_wall × 0.70`;
- guide transition: radius start + plate-follow depth;
- maximum guide reach: transition + guide-cap depth.

## 7. Tube clips

Tube-clip placement is a separate physical design requirement and is an explicit
profile/custom setting. The selected offset must still be validated against the
available plate envelope so a smaller profile cannot leave a clip unsupported or
unnecessarily protruding.

## 8. Component consistency

Middle, horizontal-edge and corner couplers must use the same shared helpers for:

- panel fit coordinates;
- plate radii;
- guide-wall clearance;
- guide free-end construction;
- tube-clip envelope rules where applicable.

A component may transform or crop the shared geometry for its topology, but it
must not redefine the underlying fit dimensions.

## 9. Verification before accepting a geometry change

At minimum check:

- small middle coupler, angled view;
- small horizontal-edge coupler, angled view;
- small corner coupler, angled view;
- medium middle coupler as a regression check;
- XY fit cross sections for middle and horizontal edge;
- the full rear-fit verification render.

The reference drawings remain the coordinate-system check. The angled and
cross-section renders are the printable-geometry check.

## Guide end geometry

The guide is derived from the same rounded plate profile as the coupler body. After subtracting the authoritative HUB75 rear keep-out plus print clearance, the exposed thin-guide ends are softly rounded. The guide follows the plate edge into its radius and terminates smoothly, without a square cut, wedge, cusp, or separate analytic cap. The same construction is used for small, medium and large; only the resolved profile dimensions change.

### Local free-end rounding

Guide-end rounding must be a **local** operation. The fitted guide shell remains authoritative over its full length. Only the free-end zone may be rounded; a shrink/expand operation must never be applied to the complete guide because that can erase the thin `small` guide. Both the outside and inside guide contours must turn around the free plate end; a square inner end face is not acceptable.

The rounded cap must be constructed as a **positive local mask/cap** over the authoritative fitted shell. `offset(delta=-r)` is forbidden for guide-end shaping, including inside a local end zone.

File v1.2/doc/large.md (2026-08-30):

# Coupler profile — Large

> The model and documentation were developed with the assistance of ChatGPT.

## Profile preset values

These are the fixed values selected by the `large` profile. The same fields are editable when `custom` is selected in the OpenSCAD Customizer.

| Setting | Value |
|---|---:|
| Profile envelope | 100 × 100 mm |
| Wall thickness | 6 mm |
| Guide height | 10 mm |
| Base thickness | 4 mm |
| Corner radius | 10 mm |
| Edge radius | 5 mm |
| Tube clip offset | 25 mm |

## Derived guide geometry

These values are **calculated**, not independent profile settings. They are shown only to make the geometry easier to verify.

| Derived value | Formula | Result |
|---|---|---:|
| Start of plate edge radius | `profile_size / 2 - edge_radius` | 45 mm |
| Plate-follow depth | `wall_thickness × 0.30` | 1.8 mm |
| Own cap depth | `wall_thickness × 0.70` | 4.2 mm |
| Maximum guide reach | radius start + follow + cap | 51 mm |

## Side by side

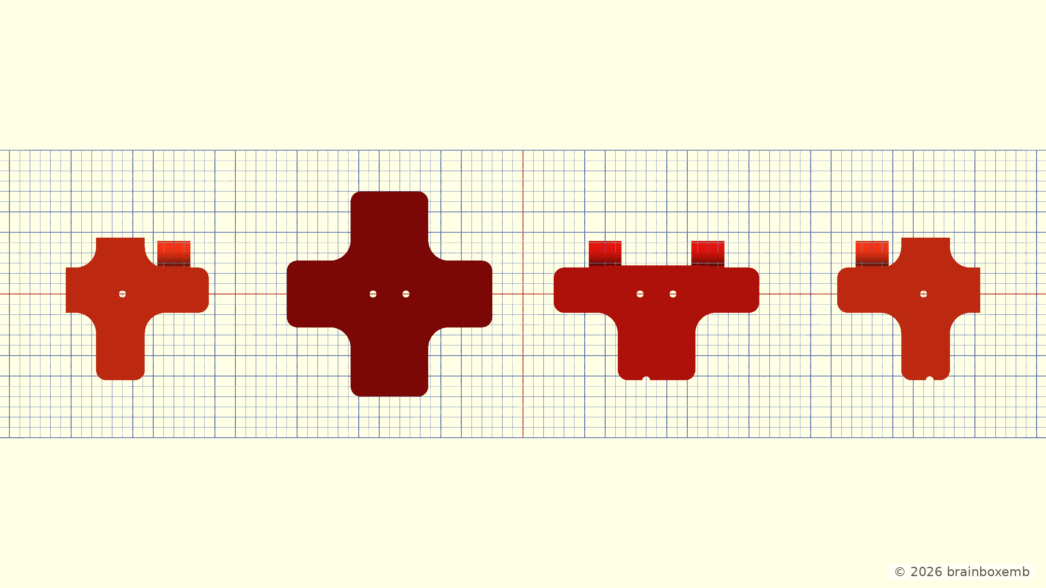
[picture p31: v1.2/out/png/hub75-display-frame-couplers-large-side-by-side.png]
V1.2 Large couplers side by side


## Stacked

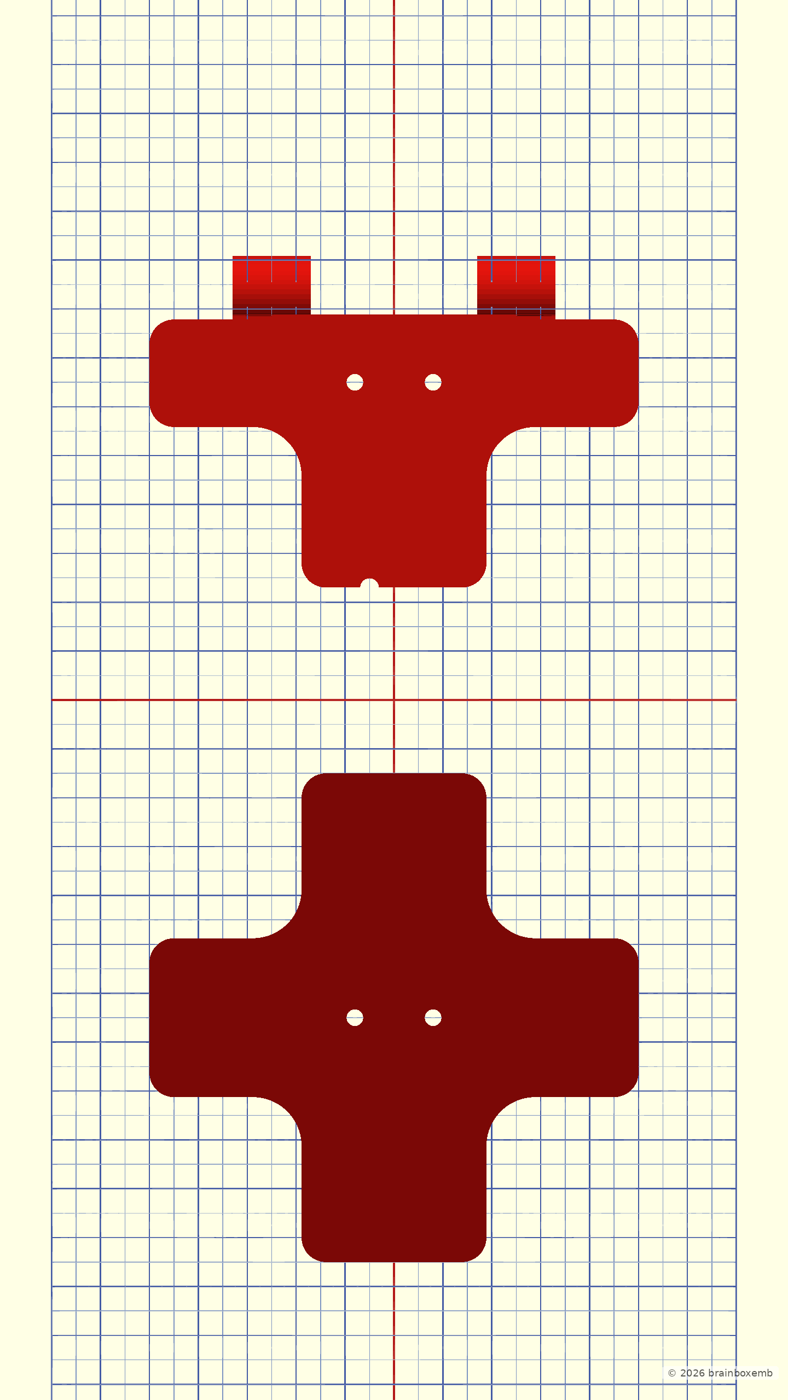
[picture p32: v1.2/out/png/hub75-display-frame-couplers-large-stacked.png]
V1.2 Large couplers stacked


## Middle panel coupler

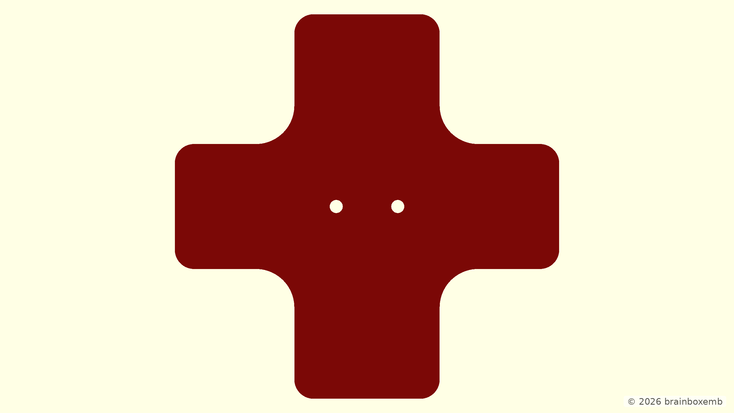
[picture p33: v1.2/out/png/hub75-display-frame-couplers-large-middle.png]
V1.2 Large middle panel coupler


## Horizontal edge panel coupler

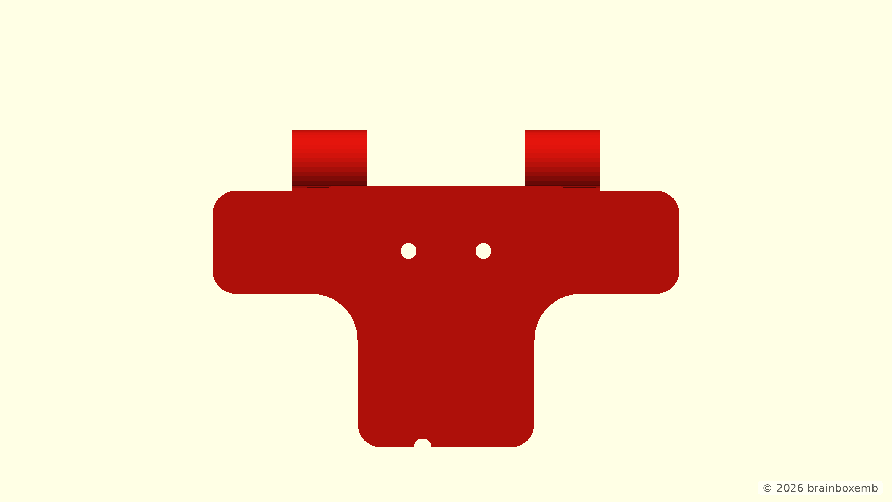
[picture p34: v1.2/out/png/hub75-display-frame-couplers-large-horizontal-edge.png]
V1.2 Large horizontal edge panel coupler


## Left corner edge panel coupler

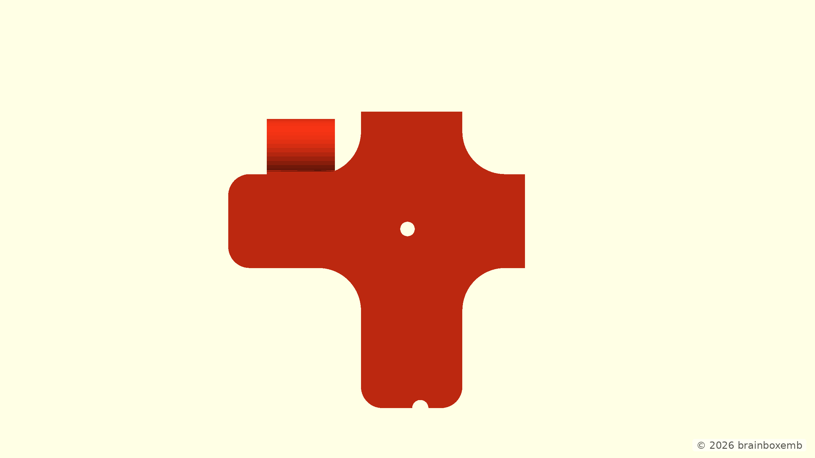
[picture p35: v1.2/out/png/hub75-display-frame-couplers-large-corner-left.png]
V1.2 Large left corner edge panel coupler


## Right corner edge panel coupler

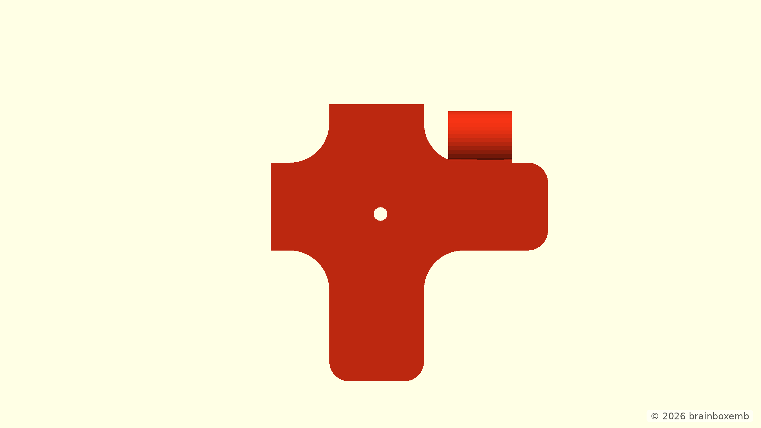
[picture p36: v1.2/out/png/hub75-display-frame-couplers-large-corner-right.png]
V1.2 Large right corner edge panel coupler


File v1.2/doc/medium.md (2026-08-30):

# Coupler profile — Medium

> The model and documentation were developed with the assistance of ChatGPT.

## Profile preset values

These are the fixed values selected by the `medium` profile. The same fields are editable when `custom` is selected in the OpenSCAD Customizer.

| Setting | Value |
|---|---:|
| Profile envelope | 80 × 80 mm |
| Wall thickness | 4 mm |
| Guide height | 6 mm |
| Base thickness | 3 mm |
| Corner radius | 8 mm |
| Edge radius | 4 mm |
| Tube clip offset | 25 mm |

## Derived guide geometry

These values are **calculated**, not independent profile settings. They are shown only to make the geometry easier to verify.

| Derived value | Formula | Result |
|---|---|---:|
| Start of plate edge radius | `profile_size / 2 - edge_radius` | 36 mm |
| Plate-follow depth | `wall_thickness × 0.30` | 1.2 mm |
| Own cap depth | `wall_thickness × 0.70` | 2.8 mm |
| Maximum guide reach | radius start + follow + cap | 40 mm |

## Side by side

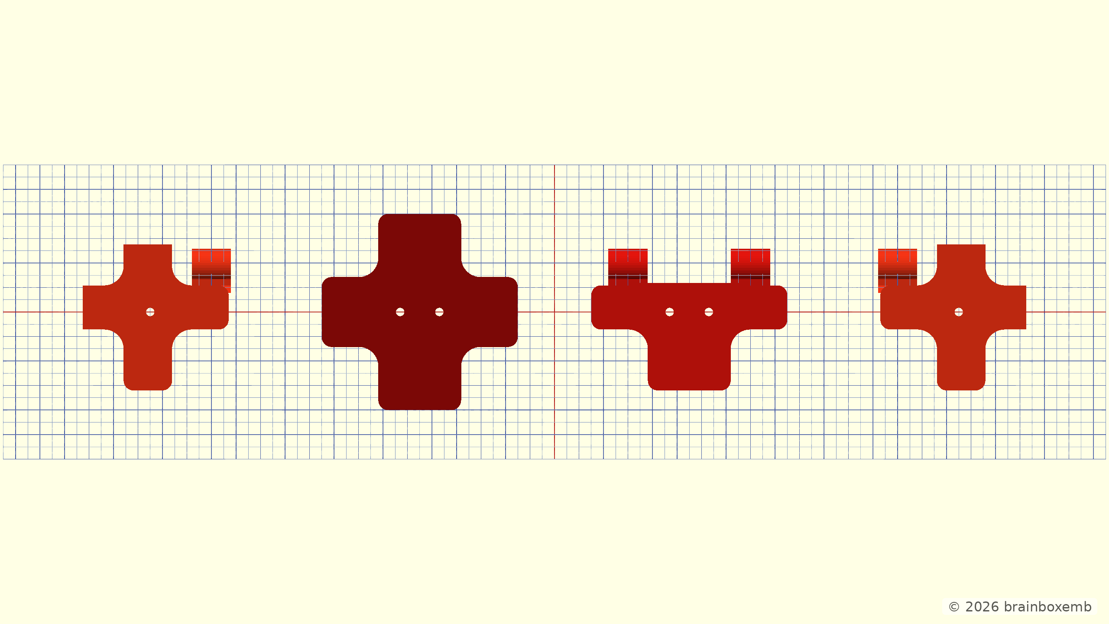
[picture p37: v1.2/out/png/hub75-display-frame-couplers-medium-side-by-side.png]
V1.2 Medium couplers side by side


## Stacked

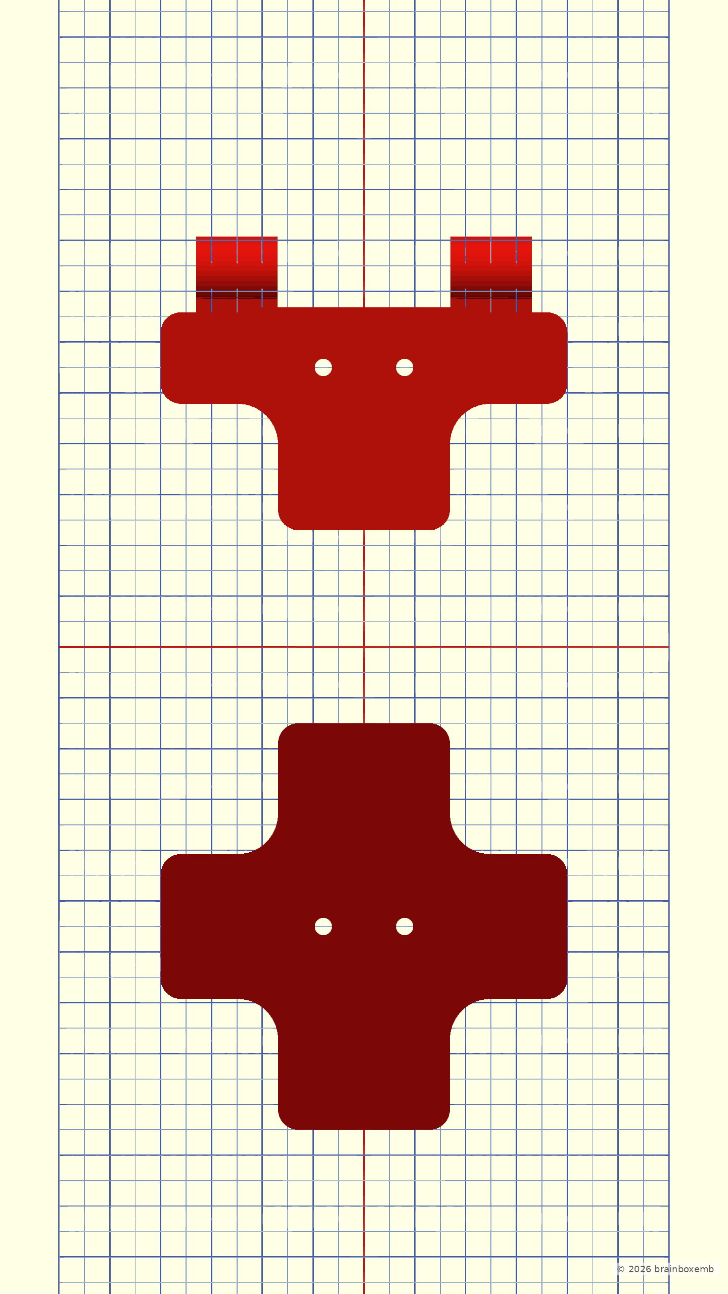
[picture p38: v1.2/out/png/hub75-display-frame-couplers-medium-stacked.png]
V1.2 Medium couplers stacked


## Middle panel coupler

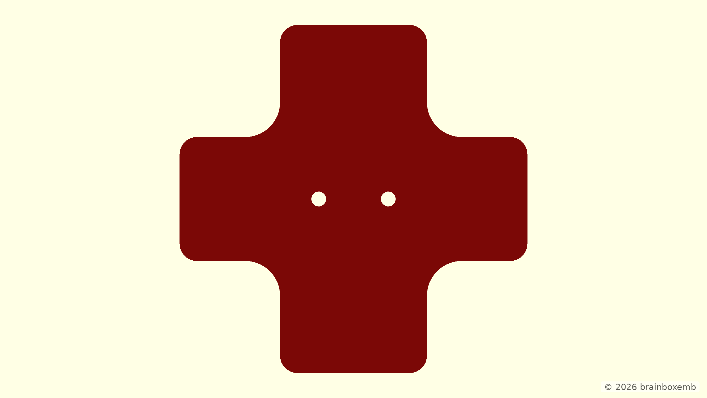
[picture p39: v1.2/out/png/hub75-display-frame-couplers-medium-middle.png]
V1.2 Medium middle panel coupler


## Horizontal edge panel coupler

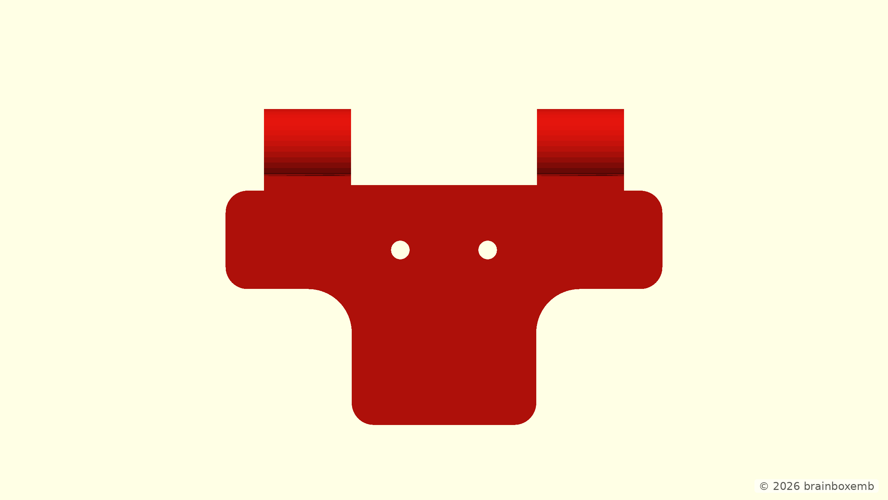
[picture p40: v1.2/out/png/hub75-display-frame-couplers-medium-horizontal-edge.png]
V1.2 Medium horizontal edge panel coupler


## Left corner edge panel coupler

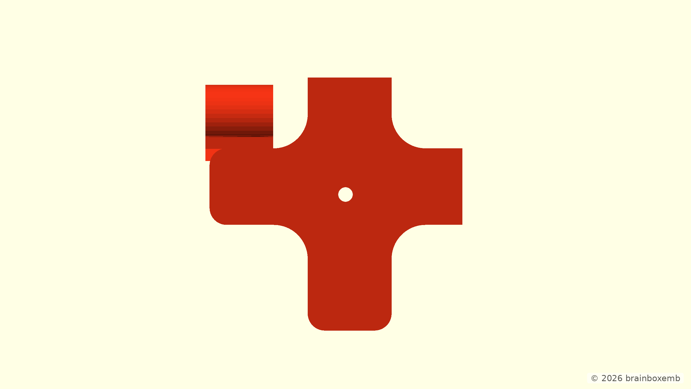
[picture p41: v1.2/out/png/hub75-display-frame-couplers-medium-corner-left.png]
V1.2 Medium left corner edge panel coupler


## Right corner edge panel coupler

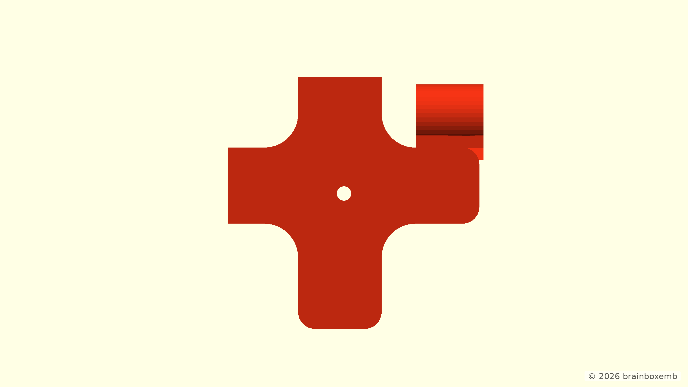
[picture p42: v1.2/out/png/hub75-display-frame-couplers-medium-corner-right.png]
V1.2 Medium right corner edge panel coupler


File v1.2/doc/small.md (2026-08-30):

# Coupler profile — Small

> The model and documentation were developed with the assistance of ChatGPT.

## Profile preset values

These are the fixed values selected by the `small` profile. The same fields are editable when `custom` is selected in the OpenSCAD Customizer.

| Setting | Value |
|---|---:|
| Profile envelope | 60 × 60 mm |
| Wall thickness | 2 mm |
| Guide height | 4 mm |
| Base thickness | 2 mm |
| Corner radius | 6 mm |
| Edge radius | 3 mm |
| Tube clip offset | 18 mm |

## Derived guide geometry

These values are **calculated**, not independent profile settings. They are shown only to make the geometry easier to verify.

| Derived value | Formula | Result |
|---|---|---:|
| Start of plate edge radius | `profile_size / 2 - edge_radius` | 27 mm |
| Plate-follow depth | `wall_thickness × 0.30` | 0.6 mm |
| Own cap depth | `wall_thickness × 0.70` | 1.4 mm |
| Maximum guide reach | radius start + follow + cap | 29 mm |

## Side by side

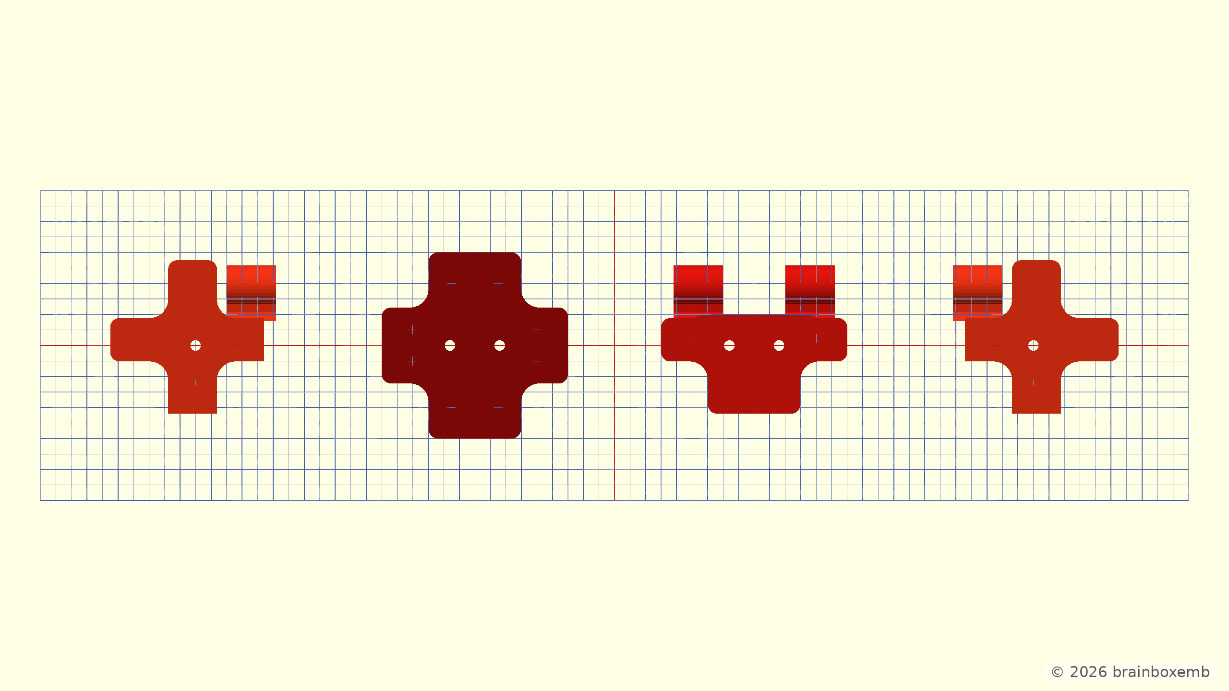
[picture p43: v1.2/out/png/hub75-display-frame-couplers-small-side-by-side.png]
V1.2 Small couplers side by side


## Stacked

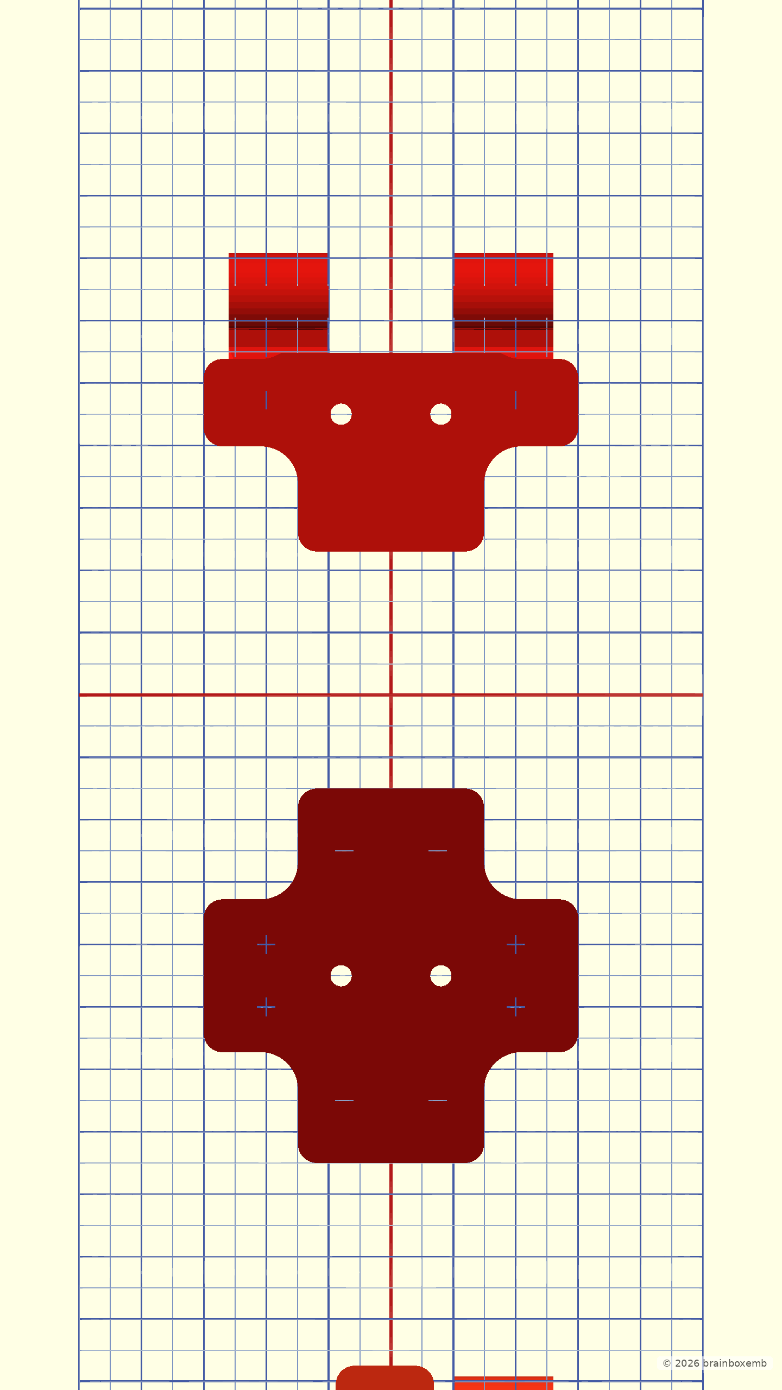
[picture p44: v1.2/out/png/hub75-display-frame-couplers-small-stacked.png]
V1.2 Small couplers stacked


## Middle panel coupler

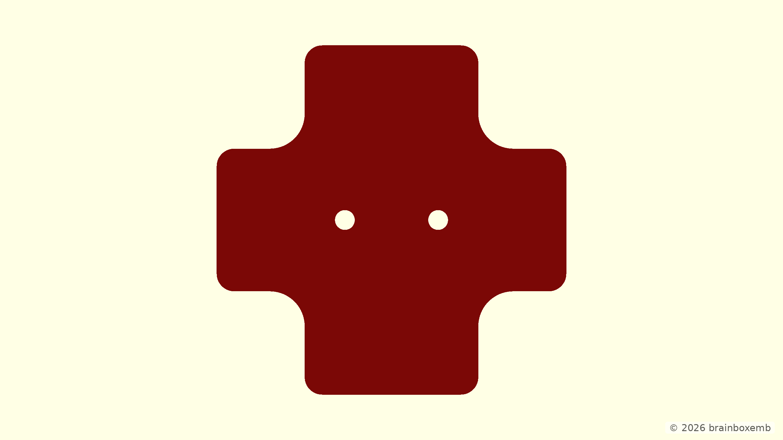
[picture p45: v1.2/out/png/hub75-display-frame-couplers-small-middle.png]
V1.2 Small middle panel coupler


## Horizontal edge panel coupler

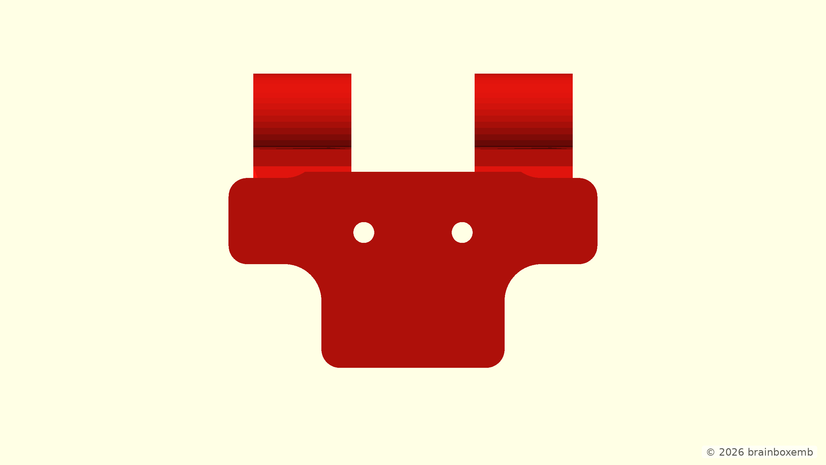
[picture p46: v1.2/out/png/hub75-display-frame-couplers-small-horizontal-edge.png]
V1.2 Small horizontal edge panel coupler


## Left corner edge panel coupler

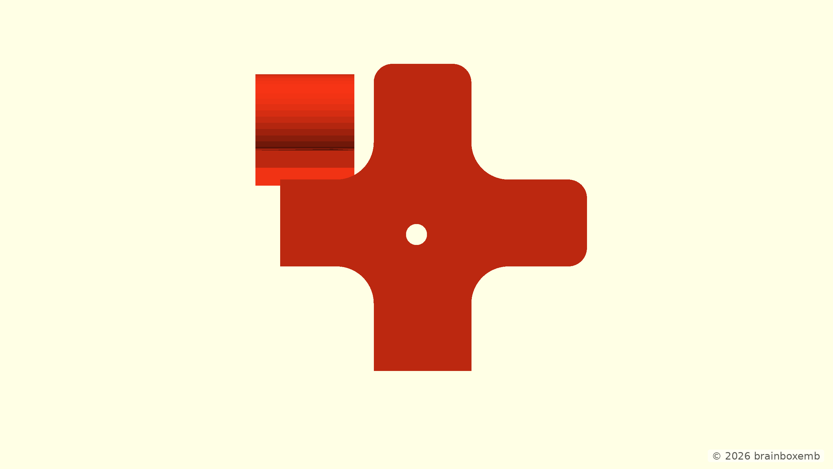
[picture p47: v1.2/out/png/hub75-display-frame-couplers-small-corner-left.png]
V1.2 Small left corner edge panel coupler


## Right corner edge panel coupler

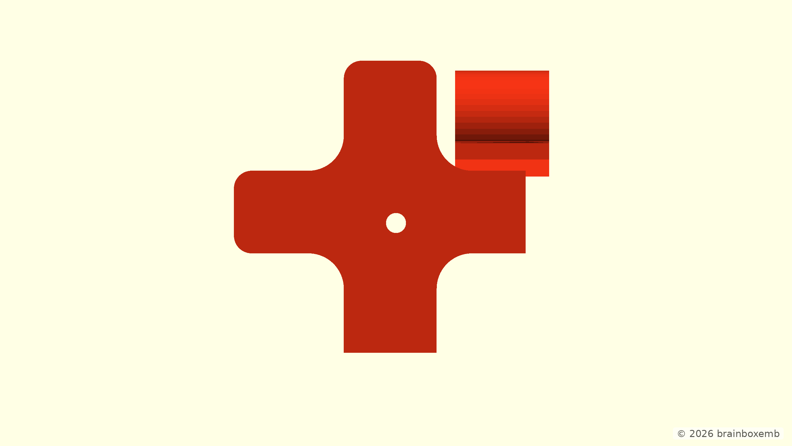
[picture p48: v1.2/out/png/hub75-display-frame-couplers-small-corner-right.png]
V1.2 Small right corner edge panel coupler


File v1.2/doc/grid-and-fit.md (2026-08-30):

# Grid and fit rules

The V1.2 coupler family uses two different geometric references deliberately:

- **Nominal panel grid:** exactly 160 × 320 mm in this portrait assembly. Panel centres and all coupler reference/seam positions are placed on this grid.
- **Physical panel geometry:** 159.70 × 319.71 mm plus the STEP-derived rear housing taper. This geometry is used only for local fit, guide and locator dimensions.

## Rear seam locator

The seam rib/locator does **not** use the 0.30 mm front/body gap. It engages at the rear mounting plane, where the housing has tapered inward by the STEP-derived outer inset. Therefore the usable rear seam is larger.

For the current panel model:

- nominal X pitch: 160.00 mm
- physical body width: 159.70 mm
- rear outer inset: about 1.248 mm per side
- rear seam gap: about 2.80 mm
- print clearance: 0.25 mm per mating side
- locator width: about 2.30 mm

The middle and horizontal-edge couplers use the same shared calculation. The locator is centred exactly on the nominal 160 mm grid seam. Its maximum width at the coupler base comes from the physical rear seam minus the fixed print clearance. From that base width the complete locator height tapers symmetrically toward a narrower insertion tip; there is no separate straight body plus short lead-in section.

The selected small/medium/large coupler profile changes plate, wall and guide dimensions, but it does not move the nominal grid or scale the physical print clearance.

## Rear mounting-plane rail fit

Coupler guide clearance is evaluated against the **actual rail footprint at the rear mounting plane**, not against the wider rail dimensions at the start of the tapered rear housing. The bay openings remain vertical while the outside housing tapers inward, so the outer side/end rails become narrower at the mating face.

For the current panel model this means approximately:

- rear outer inset X: 1.248 mm
- rear outer inset Z: 1.249 mm
- side rail at mounting plane: 12.50 - 1.248 = **11.252 mm**
- normal end rail at mounting plane: 10.75 - 1.249 = **9.501 mm**
- internal X-seam rail keep-out: 2 × 11.252 + 2.795 = **25.300 mm**

Earlier guide code used the 12.50 mm and 10.75 mm reference widths directly at the rear face. That made the keep-out too large by about 1.25 mm at each outside rail face and made corner/edge fits appear inconsistent. Middle, horizontal-edge and corner couplers now derive their mating keep-outs from the same rear-plane dimensions, while retaining the fixed 0.25 mm printable clearance per mating side.

## Rear fit verification view

The full rear fit verification render deliberately hides the front pixel face and PCB of each HUB75 panel. Only the rear structural panel frame is shown in grey. This makes the individual panel perimeter, nominal seams and coupler engagement visible instead of merging the five panels into one large grey rectangle.

## Local XY fit cross-sections

The middle and horizontal-edge diagnostic cross-sections are cut with a thin slab **parallel to the XY plane** at a fixed Z coordinate. The Z station is chosen just inboard of the horizontal coupler arm. This exposes the seam locator and panel rear profile instead of showing a vertical XZ/YZ section.

These views are intended to verify:

- the locator centre is exactly on the nominal seam;
- equal clearance exists to the physical panel geometry on both sides;
- the locator width follows the rear seam gap rather than the front body gap;
- guide and cut-out geometry still follows the physical panel after grid-position changes.

## Canonical 2D coordinate references

Before changing coupler fit geometry, the V1.2 model now exposes standalone 2D engineering references under `v1.2/cad/references/`. Every panel remains centred around its own local `(0,0)` and component references only translate that canonical model.

The drawings distinguish four boundaries which must not be mixed:

1. nominal 160 × 320 mm portrait grid cell;
2. physical front/body outside contour;
3. physical rear outside contour at the mounting plane;
4. physical rear **inner rail edge**, i.e. the start of the electronics opening.

The rear outer and rear inner boundaries together define the real mating rail width used by coupler keep-outs. The reference set includes panel, middle, horizontal-edge, top-left corner and top-right corner coordinate views.

All reference entrypoints reuse the same shared reference-grid implementation as the top-level CAD views. The grid remains independently switchable from the Customizer when a reference `.scad` file is opened directly.

## Canonical panel fit coordinates

All mating geometry now passes through `cad/components/_lib/panel_fit_geometry.scad`.
`hub75_panel.scad` remains the authoritative physical panel model; the fit
adapter only translates that model into one shared panel-centred coordinate
system for the middle, horizontal-edge and corner couplers and for the 2D
reference drawings.

The adapter keeps the nominal placement cell, physical front outer edge, rear
outer edge and rear inner/opening edge separate.  Component files should not
reconstruct those boundaries with local offsets.

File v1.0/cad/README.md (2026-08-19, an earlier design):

# HUB75 Display Frame — Modular OpenSCAD Project

The model and documentation were developed with the assistance of ChatGPT.

This version deliberately narrows the project to the aluminium HUB75 display frame and the parts mounted directly to that frame.

The former wooden enclosure, EPDM/plexiglass enclosure stack, top-cap parts and plastic handle have been removed. This project now contains only the active modular frame model; the old monolithic/legacy source is no longer included.

## Structure

```text
.
├── main.scad
├── config/
│   └── project_config.scad
├── components/
│   ├── ... individual frame-related parts ...
│   └── _lib/
│       └── fasteners.scad
├── assemblies/
│   ├── frame_assembly.scad
│   ├── panels_assembly.scad
│   ├── hardware_assembly.scad
│   ├── frame_system_assembly.scad
│   └── ... optional frame-mounted electronics ...
```

## Working model

- Open `main.scad` for the active frame model.
- The default `frame_system` view shows the aluminium frame, HUB75 panels and their mechanical mounting hardware.
- ESP32 and power-supply assemblies remain available as optional frame-mounted subsystems, but are hidden by default while the mechanical frame is being developed.
- Open any file in `components/` to render and tune that part independently.
- Open any file in `assemblies/` to inspect a subassembly independently.
- Shared dimensions and mounting interfaces live in `config/project_config.scad`.
- Placement belongs in assemblies, not in component geometry.

## Current scope

The active design now focuses on:

- 20 × 20 mm aluminium extrusion frame;
- five HUB75 panels;
- panel-to-frame brackets;
- vertical TS35 DIN rails at panel seams;
- cable clips and ribbon-cable routing;
- fasteners associated with those frame-mounted parts.

The enclosure can be reconsidered later, after the frame concept has been developed further.

## OpenSCAD entry points

`view_mode` is deliberately the first Customizer section in `main.scad`, so changing the active view is the first control shown when working with the complete model.

Assemblies are loaded by `main.scad` with `use <...>`. Visibility settings from `main.scad` are passed explicitly into the assemblies, so controls such as `show_esp32`, `show_power_supply`, `show_brackets` and `show_bolts` work reliably. Each assembly can still contain its own standalone preview settings without affecting the complete model. No special `assembly_library` parameter is required.

## Documentation renders

V1.0 contains fixed OpenSCAD camera files under `renders/` so local and CI-generated documentation images use the same viewpoints.

```text
renders/
├── front.scad
├── front_angled.scad
├── rear.scad
├── rear_angled.scad
├── exploded_rear.scad
└── exploded_rear_angled.scad
```

The exploded view keeps the aluminium frame as the reference layer, moves the HUB75 panels toward the front and moves the frame-mounted hardware toward the rear.

From the repository root, the official PNG set can be generated with:

```bash
bash cad/v1.0/scripts/render_pngs.sh out/v1.0/png
```

The script creates:

```text
hub75-display-frame-front.png
hub75-display-frame-front-angled.png
hub75-display-frame-rear.png
hub75-display-frame-rear-angled.png
hub75-display-frame-exploded-rear.png
hub75-display-frame-exploded-rear-angled.png
```

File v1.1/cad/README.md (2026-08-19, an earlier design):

# HUB75 Display Frame — V1.1 CAD

The model and documentation were developed with the assistance of ChatGPT.

V1.1 develops a modular 3D-printed structural frame for five HUB75 panels, reinforced by continuous aluminium tubes along the top and bottom.

## First modular-frame concept

The first frame concept uses the nominal HUB75 dimensions as a structural grid:

- nominal HUB75 cell: 160 × 320 mm;
- printed structural module: 160 × 160 mm;
- five panels therefore form a 5 × 2 grid of ten printed modules;
- the measured panel PCB remains slightly smaller than the nominal grid;
- each module has a large central opening to reduce material and keep the rear connectors accessible;
- adjacent modules use asymmetric dovetail-style interlocks: the female/pocket module owns 5 mm across the nominal grid line, the male module is cut back 5 mm, and the dovetail spans 10 mm total depth;
- separate seam joiners use the existing HUB75 screw pairs to connect neighbouring panels and locate into the printed modules;
- four related red shades are repeated across the OpenSCAD assembly view to make neighbouring frame modules and four-module crossings easier to distinguish;
- the top and bottom module rows include two integrated snap clips per module;
- two continuous 800 mm aluminium tubes (Ø10 × 1 mm wall) snap into those clips to add longitudinal stiffness and alignment;
- the top and bottom frame modules extend straight beyond the panel edges;
- in side view each circular tube clamp sits beside this straight extension, with a small overlap into the plate for a direct connection;
- the aluminium tube runs perpendicular to these extensions over the full 800 mm width;
- the structural clips occupy only short sections of the tube, so later front-border parts can use the free tube sections as their own clip interface;
- the remaining outside perimeter is kept available for that separate visible border.

The mounting holes follow the measured HUB75 mounting-hole positions. The internal printed joints are deliberately offset from the nominal 160 mm grid: one module owns 5 mm across the grid line, while the mating module is cut back by the same amount. The puzzle feature then continues to 10 mm total depth. This means the printed structural seam no longer coincides exactly with the HUB75 panel/grid seam.

At the horizontal centre joint the two nearby HUB75 screws are divided diagonally between the printed modules. At a four-module crossing the intended ownership is:

```text
A | B
--+--
C | D
```

The first screw belongs to **A** and the second screw belongs to **D**. Around the D-owned screw, D takes one continuous region from B and grows upward through the horizontal joint. A is left untouched by this transfer. At the lower corner, the D tab returns directly to the normal D/C boundary with one 45-degree transition; there is no separately dimensioned tongue into C. C receives the matching clearance notch. Each screw hole is therefore fully contained by one printed part instead of sitting on a module boundary.

The panel-seam joiners are compact rectangular connection plates with chamfered corners, using the existing HUB75 screw pairs and locating pins into the printed modules.

## Structure

```text
.
├── main.scad
├── config/
│   └── project_config.scad
├── components/
│   ├── aluminium_stiffening_tube.scad
│   ├── frame_module.scad
│   ├── hub75_panel.scad
│   └── panel_seam_joiner.scad
└── assemblies/
    ├── display_assembly.scad
    ├── frame_modules_assembly.scad
    ├── panel_seam_joiners_assembly.scad
    ├── panels_assembly.scad
    └── stiffening_tubes_assembly.scad
```

Open `main.scad` for the complete V1.1 concept. The `exploded` view mode separates the HUB75 panels, printed frame modules and seam joiners along the depth axis. The stiffening tubes stay with the printed frame layer in the exploded view; their clamps are side-mounted to the straight top and bottom module extensions. `exploded_distance` controls the spacing. Individual component files can also be opened independently for tuning and inspection.

## Tube clamp orientation

The tube snap clamps are side-mounted to the straight frame extensions. In side view the clamp opening faces away from the plate extension, rather than upward or downward.

### Current joint refinement

The current module joints use a 5 mm asymmetric ownership strip with a 10 mm total puzzle depth, so the real printed seam is offset from the nominal panel/grid boundary. The vertical panel seam joiner remains a single compact rectangular plate with chamfered corners.

## Dovetail joint update

The module interlock is now generated from one dovetail profile. The 45-degree flanks start directly at the narrow root and finish with a 1.5 mm straight tip. Female pockets are derived from the same profile with print clearance added, then transformed to the mating edge orientation. This keeps the male and female geometry complementary instead of constructing them independently.

At four-module intersections the middle screw pair is intentionally owned diagonally. The first screw is contained by A and the second by D. The D-owned region is one continuous profile: the main area replaces B around the second screw, then returns directly to the normal D/C boundary with a single 45-degree flank. A is not cut by this transition.

Current crossing refinement: A owns the first middle screw through the normal overlap; D owns the second through a tab into B. The lower corner of that tab tapers directly back to the normal D/C boundary with one 45-degree flank, without an extra tongue.

## Documentation renders

The official documentation views are defined inside the CAD project rather than in the CI workflow:

```text
renders/
├── front.scad
├── front_angled.scad
├── rear.scad
├── rear_angled.scad
├── exploded_rear.scad
└── exploded_rear_angled.scad
```

The angled front and rear views are a matched pair. The rear camera is the exact mirrored counterpart of the front camera, so both images use the same apparent viewing angle. The exploded rear-angled view uses that same rear camera, making the assembled and exploded images directly comparable.

The helper script renders all six documentation views:

```bash
bash cad/v1.1/scripts/render_pngs.sh out/v1.1/png
```

It generates:

```text
out/v1.1/png/
├── hub75-display-frame-front.png
├── hub75-display-frame-front-angled.png
├── hub75-display-frame-rear.png
├── hub75-display-frame-rear-angled.png
├── hub75-display-frame-exploded-rear.png
└── hub75-display-frame-exploded-rear-angled.png
```

The repository-level GitHub Actions workflow belongs at:

```text
.github/workflows/render-openscad-v1.1.yml
```

It can be run manually and also runs when files below `cad/v1.1/` change. The generated PNG files are committed back to `out/v1.1/png/` so they can be referenced directly by the repository README.

### Exploded view

The exploded view separates the construction while preserving the same overall orientation:

- HUB75 panels move forward;
- the ten printed frame modules fan out slightly in X and Z to expose their interlocking edges;
- panel-seam joiners move rearward as a separate layer;
- the top aluminium tube moves upward out of its clips;
- the bottom aluminium tube moves downward out of its clips.

`exploded_distance` in `main.scad` controls the exploded spacing.

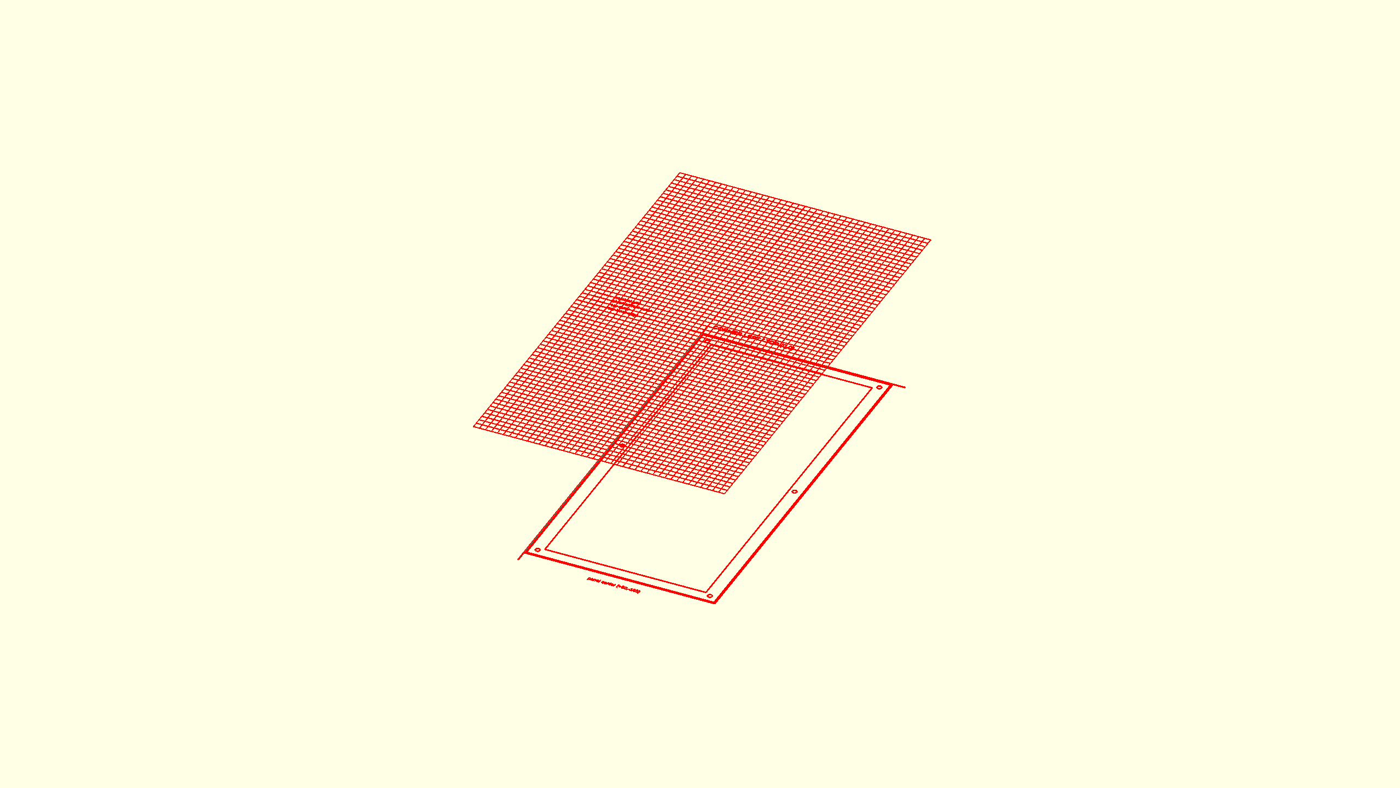
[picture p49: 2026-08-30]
v1.2/out/reference/hub75-display-frame-corner-left-reference.png

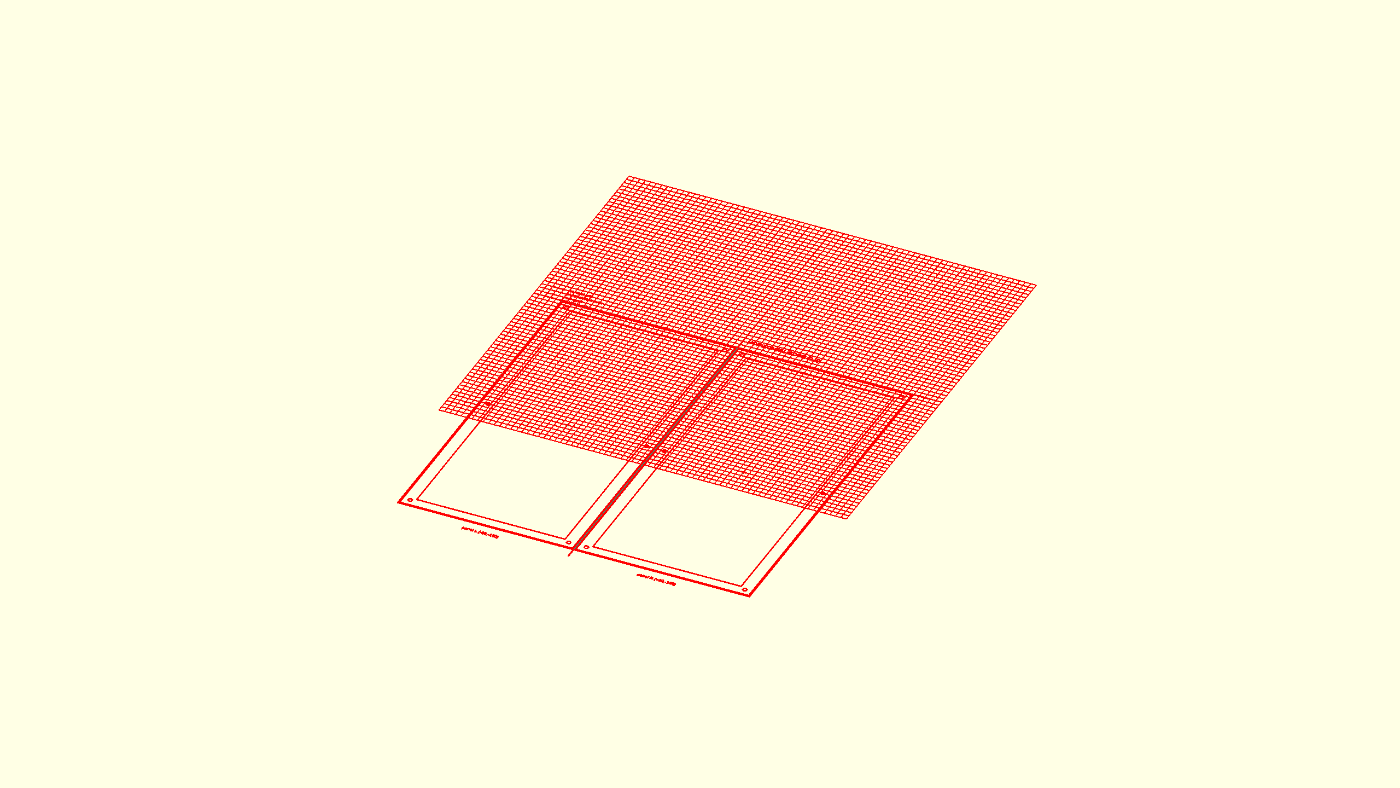
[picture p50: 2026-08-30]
v1.2/out/reference/hub75-display-frame-horizontal-edge-reference.png

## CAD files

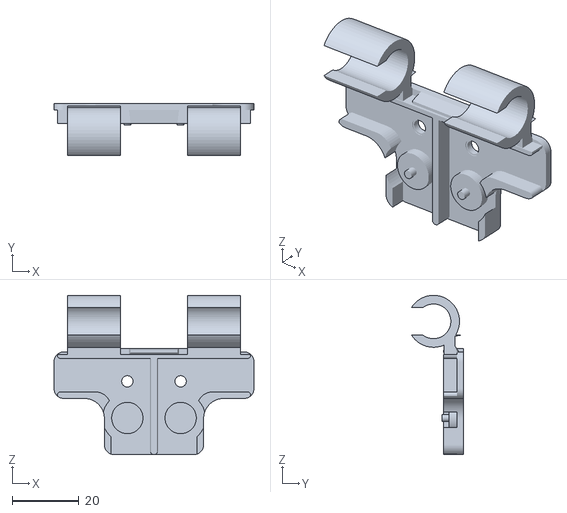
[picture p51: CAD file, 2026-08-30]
v1.2/out/stl/hub75-display-frame-horizontal-edge-panel-coupler-small.stl
60.0 x 15.6 x 47.8

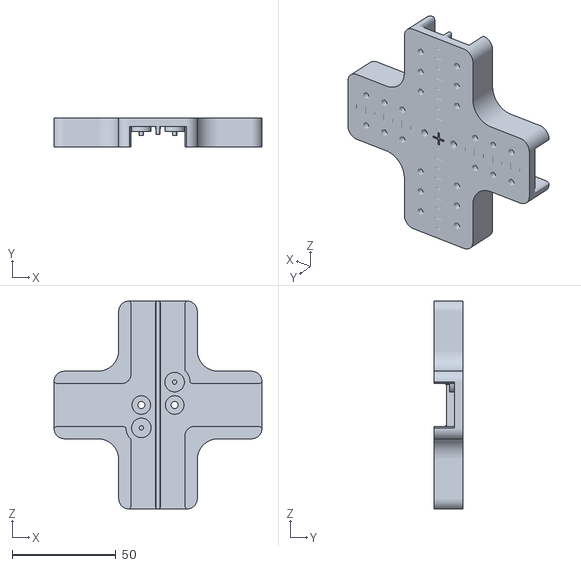
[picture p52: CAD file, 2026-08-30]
v1.2/out/stl/hub75-display-frame-middle-panel-coupler-large.stl
100.0 x 14.0 x 100.0

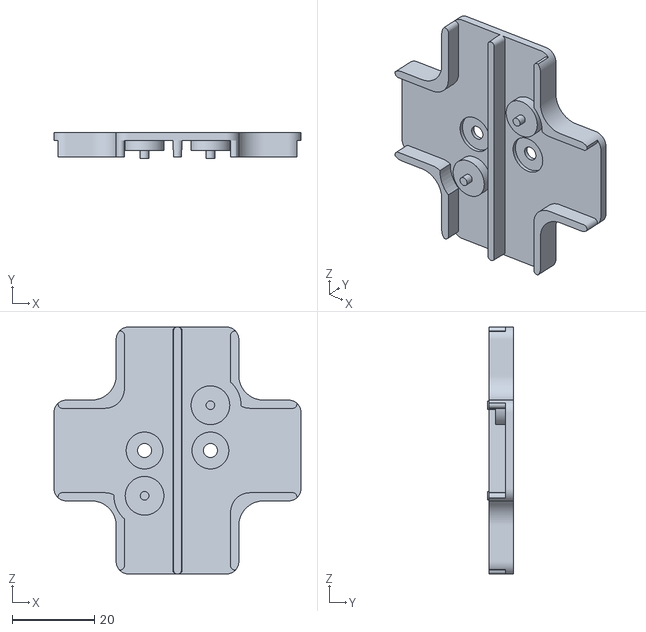
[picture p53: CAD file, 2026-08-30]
v1.2/out/stl/hub75-display-frame-middle-panel-coupler-small.stl
60.0 x 6.40 x 60.0

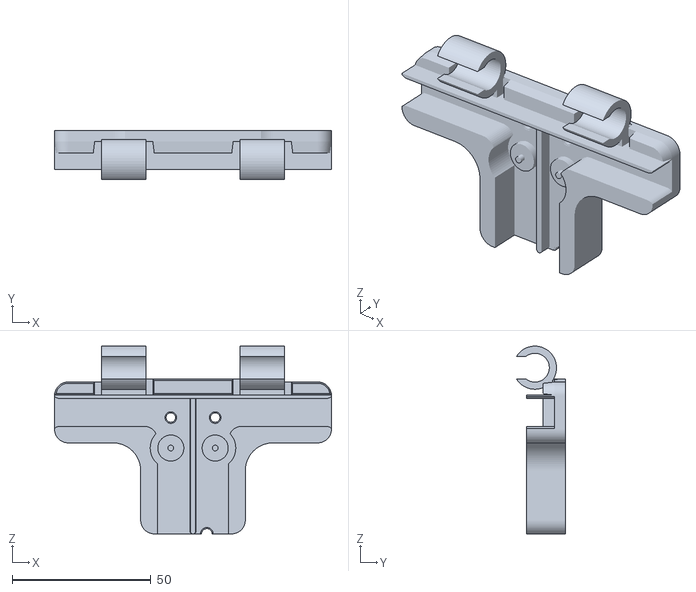
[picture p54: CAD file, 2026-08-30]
v1.2/out/stl/hub75-display-frame-horizontal-edge-panel-coupler-large.stl
100.0 x 17.6 x 67.8

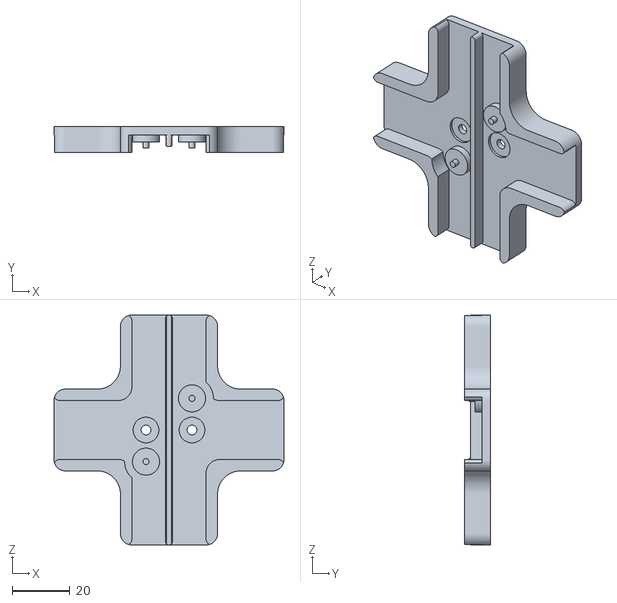
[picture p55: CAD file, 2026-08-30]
v1.2/out/stl/hub75-display-frame-middle-panel-coupler-medium.stl
80.0 x 9.00 x 80.0

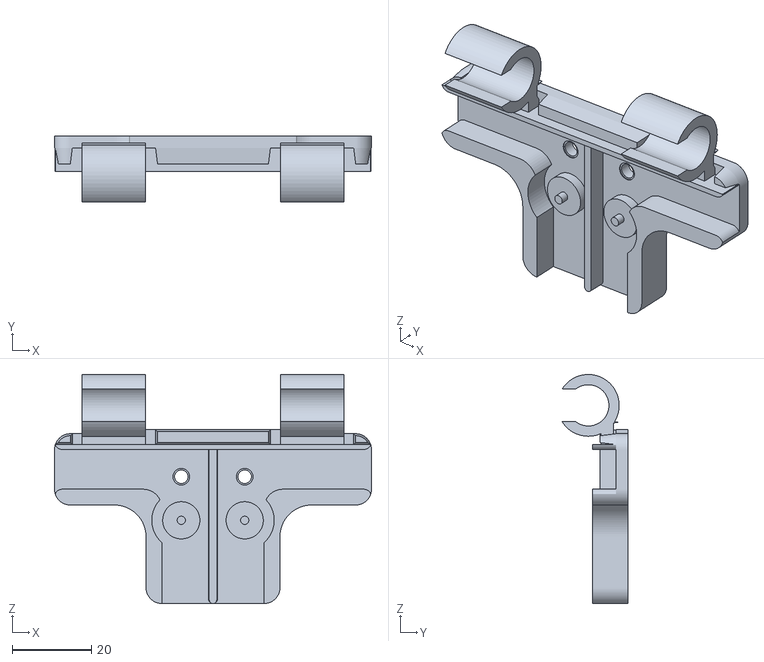
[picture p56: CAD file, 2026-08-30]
v1.2/out/stl/hub75-display-frame-horizontal-edge-panel-coupler-medium.stl
80.0 x 16.6 x 57.8

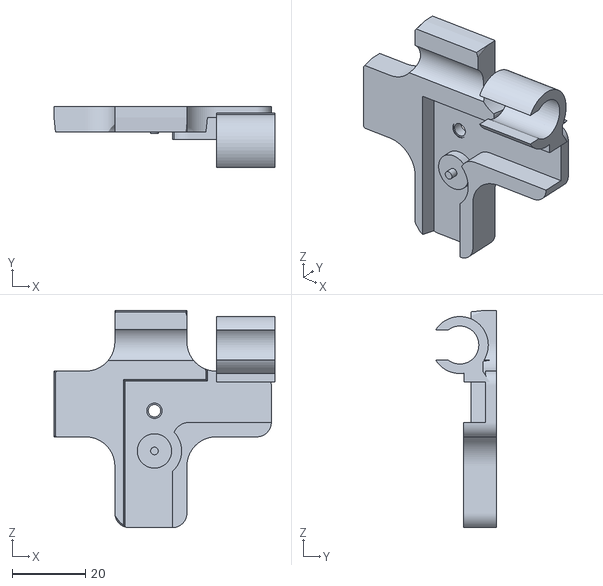
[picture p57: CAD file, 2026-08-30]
v1.2/out/stl/hub75-display-frame-corner-edge-panel-coupler-left-medium.stl
60.5 x 16.6 x 59.5

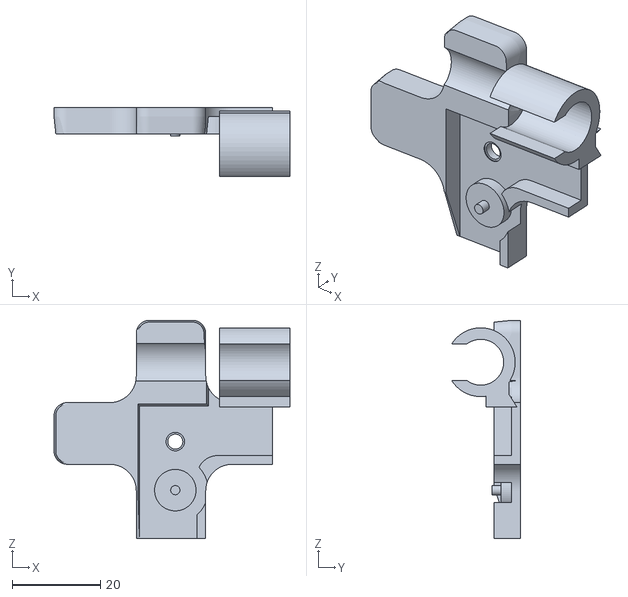
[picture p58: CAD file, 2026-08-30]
v1.2/out/stl/hub75-display-frame-corner-edge-panel-coupler-left-small.stl
53.5 x 15.6 x 49.5

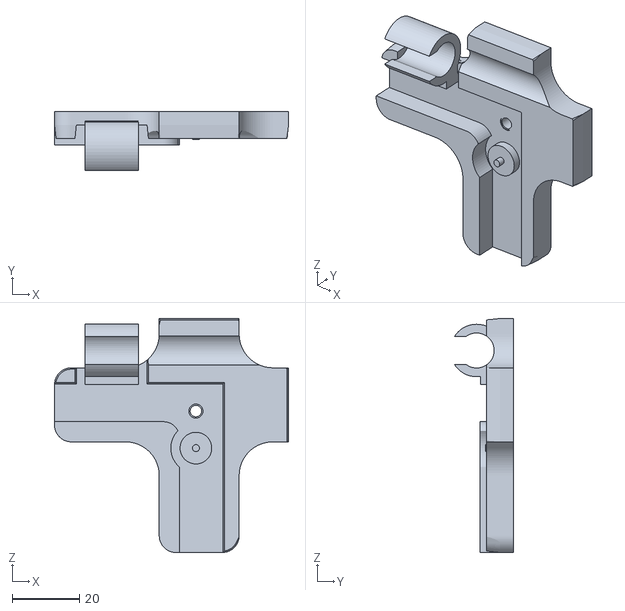
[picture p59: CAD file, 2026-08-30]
v1.2/out/stl/hub75-display-frame-corner-edge-panel-coupler-right-large.stl
69.5 x 17.6 x 69.5

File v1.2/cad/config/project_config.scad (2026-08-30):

// HUB75 display frame - V1.2 project / assembly configuration
//
// IMPORTANT ARCHITECTURE RULE
// ---------------------------
// This file contains only choices that describe THIS display assembly or its
// presentation. Physical dimensions of a HUB75 panel, tube, clip or coupler
// belong to those components and are exposed through their public functions.

use <../components/hub75_panel.scad>
use <../components/tube_clip.scad>
use <../components/aluminium_tube.scad>

$fn = 48;

/* [Panel array] */
panel_count = 5;

// Data-chain order is defined from the REAR of the assembled display.
rear_chain_start_side = "left"; // [left,right]
first_panel_input_side = "top"; // [top,bottom]

// Exact placement grid.  The supplied panel is nominally 320 x 160 mm in
// landscape orientation; this project uses it portrait, so X pitch is 160 mm
// and Z pitch is 320 mm.  The physical body is slightly smaller and is centred
// inside this nominal cell.  Coupler references MUST follow this grid, never
// the physical panel edge.
panel_grid_pitch_x = hub75_panel_nominal_width();
panel_grid_pitch_z = hub75_panel_nominal_height();
panel_pitch = panel_grid_pitch_x; // backwards-compatible assembly alias

// Project coordinate system:
//   X = 0 : centre of the complete physical panel array
//   Y = 0 : rear mounting plane of the HUB75 panels
//   Z = 0 : centre of the HUB75 panels
// The reusable hub75_panel component keeps its own local front-face Y=0.
project_panel_rear_y = 0;

function panel_chain_number(global_index) =
    rear_chain_start_side == "left" ? panel_count - global_index : global_index + 1;

function panel_input_is_top(global_index) =
    let(chain_index = panel_chain_number(global_index) - 1)
        first_panel_input_side == "top" ? chain_index % 2 == 0 : chain_index % 2 == 1;

function panel_rotated(global_index) = !panel_input_is_top(global_index);

function display_nominal_width() = panel_count * panel_grid_pitch_x;
function display_nominal_height() = panel_grid_pitch_z;
function display_actual_width() = display_nominal_width() - hub75_panel_grid_gap_x();
function display_actual_height() = hub75_panel_height();

// Nominal grid is authoritative.  Every physical panel is centred in its
// 160 x 320 mm cell; its 0.30 x 0.29 mm undersize therefore appears as equal
// margins on both sides instead of shifting seams/couplers by half the gap.
function panel_nominal_left_x(index) = -display_nominal_width()/2 + index * panel_grid_pitch_x;
function panel_center_x(index) = panel_nominal_left_x(index) + panel_grid_pitch_x/2;
function panel_x(index) = panel_center_x(index) - hub75_panel_width()/2;
function panel_center_z() = 0;
function panel_nominal_bottom_z() = -panel_grid_pitch_z/2;
function panel_nominal_top_z() = panel_grid_pitch_z/2;
function panel_front_y() = project_panel_rear_y - hub75_panel_mounting_plane_y();
function panel_drawing_z(global_drawing_z) = global_drawing_z - hub75_panel_height()/2;
function panel_hole_z_bottom() = panel_drawing_z(hub75_panel_hole_z_bottom());
function panel_hole_z_middle() = panel_drawing_z(hub75_panel_hole_z_middle());
function panel_hole_z_top() = panel_drawing_z(hub75_panel_hole_z_top());
function panel_hole_z_positions() = [panel_hole_z_bottom(), panel_hole_z_middle(), panel_hole_z_top()];
// Internal coupler centres sit exactly on the nominal grid boundaries.
function seam_x(seam_index) = -display_nominal_width()/2 + (seam_index + 1) * panel_grid_pitch_x;

/* [Project envelope and stiffening tubes] */
// These values describe how otherwise reusable components are combined in
// THIS display. They intentionally belong to project_config.scad because the
// project-specific couplers derive their tube-clip positions from them.
display_envelope_width = 840.0;
display_envelope_height = 360.0;
tube_center_spacing = 340.0;

// Distance from the HUB75 rear mounting plane (project Y=0) toward the front
// of the panel to the centre of the Ø10 tube. With the chosen project axis,
// this becomes Y=-7 mm. A Ø10 tube then leaves 2.0 mm to the rear plane and
// 2.5 mm to the panel front face.
tube_center_from_panel_rear = 7.0;

function display_envelope_x_min() = -display_envelope_width/2;
function display_envelope_x_max() =  display_envelope_width/2;
function display_envelope_z_min() = -display_envelope_height/2;
function display_envelope_z_max() =  display_envelope_height/2;

// Y depth lines of the visual project envelope use the panel front face and
// the Y=0 rear mounting plane as clear project references.
function display_envelope_y_min() = panel_front_y();
function display_envelope_y_max() = project_panel_rear_y;

function stiffening_tube_length() = display_envelope_width;
function stiffening_tube_x() = display_envelope_x_min();
function stiffening_tube_y() = project_panel_rear_y - tube_center_from_panel_rear;
function stiffening_tube_bottom_z() = -tube_center_spacing/2;
function stiffening_tube_top_z() =  tube_center_spacing/2;

// Coupler design profiles are project-level presets. The selected profile is
// the single source of truth for all effective coupler dimensions. Three
// named presets are fixed and reproducible; selecting "custom" switches the
// model to the user-entered custom dimensions.
//
//   small  =  60 mm, 2 mm wall,  4 mm guide, 2 mm base
//   medium =  80 mm, 4 mm wall,  6 mm guide, 3 mm base
//   large  = 100 mm, 6 mm wall, 10 mm guide, 4 mm base
function coupler_profile_size_for(name) =
    name == "small" ?  60.0 :
    name == "large" ? 100.0 :
                       80.0;
function coupler_wall_thickness_for(name) =
    name == "small" ? 2.0 :
    name == "large" ? 6.0 :
                      4.0;
function coupler_guide_height_for(name) =
    name == "small" ?  4.0 :
    name == "large" ? 10.0 :
                       6.0;
function coupler_base_thickness_for(name) =
    name == "small" ? 2.0 :
    name == "large" ? 4.0 :
                      3.0;

// Shape/placement rules. These describe printable coupler geometry, not
// HUB75 panel geometry.  The named profiles define the user-visible design
// values explicitly so the fixed presets and custom mode expose the same
// conceptual controls.
//
// Names are intentionally visual:
//   corner_radius = concave transition where an arm meets the centre/body
//   edge_radius   = convex rounding at the free outside end of an arm
function coupler_corner_radius_for(name) =
    name == "small" ? 6.0 :
    name == "large" ? 10.0 :
                      8.0;
function coupler_edge_radius_for(name) =
    name == "small" ? 3.0 :
    name == "large" ? 5.0 :
                      4.0;

// Guide free-end shape.  This split is derived from the guide wall width and
// is intentionally NOT a preset value.
coupler_guide_plate_radius_share = 0.30;
coupler_guide_own_radius_share = 0.70;

// Tube-clip centre position is also an explicit profile design value.  This
// keeps the named presets consistent with the editable custom field.
function coupler_tube_clip_offset_for(name) =
    name == "small" ? 18.0 :
    name == "large" ? 25.0 :
                      25.0;

function coupler_guide_plate_follow_depth_for_wall(wall_thickness) =
    max(0, wall_thickness * min(1, max(0, coupler_guide_plate_radius_share)));

function coupler_guide_cap_depth_for_wall(wall_thickness) =
    max(0, wall_thickness * min(1, max(0, coupler_guide_own_radius_share)));

// Derived guide geometry.  The guide is not a separately configured length:
// it follows the straight plate edge to the start of edge_radius, then follows
// 30% of the guide-wall width into that radius and uses the remaining 70% for
// its own rounded cap.
function coupler_guide_transition_for_size(profile_size, edge_radius, wall_thickness) =
    max(0,
        profile_size/2 - edge_radius
        + coupler_guide_plate_follow_depth_for_wall(wall_thickness)
    );

function coupler_guide_length_for_size(profile_size, edge_radius, wall_thickness) =
    coupler_guide_transition_for_size(profile_size, edge_radius, wall_thickness)
    + coupler_guide_cap_depth_for_wall(wall_thickness);

function coupler_guide_end_radius_for_wall(wall_thickness) =
    coupler_guide_cap_depth_for_wall(wall_thickness);

function coupler_guide_length_for(name) =
    coupler_guide_length_for_size(
        coupler_profile_size_for(name),
        coupler_edge_radius_for(name),
        coupler_wall_thickness_for(name)
    );

function project_coupler_design_profile() =
    is_undef($coupler_design_profile) ? "medium" : $coupler_design_profile;
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

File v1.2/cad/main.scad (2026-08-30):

// HUB75 Display Frame - V1.2 / project coordinates and envelope V82 - comparison/profile alignment + small/medium/large/custom coupler profiles V108
//
// Simplified proof-of-concept based directly on V1.1:
// - V1.1 HUB75 panel reference retained unchanged;
// - no 160 x 160 mm printed frame modules;
// - wider top/bottom two-panel couplers;
// - four short tube clips per horizontal edge panel coupler;
// - one-screw/one-clip couplers at both display ends;
// - rounded middle panel couplers;
// - V1.1 aluminium tube size, position and 40/120 mm clip spacing retained.

include <config/project_config.scad>
use <assemblies/display_assembly.scad>
use <assemblies/panels_assembly.scad>
use <assemblies/couplers_assembly.scad>
use <assemblies/tubes_assembly.scad>
use <project_components/middle_panel_coupler.scad>
use <project_components/horizontal_edge_panel_coupler.scad>
use <project_components/corner_edge_panel_coupler.scad>
use <assemblies/rear_fit_section.scad>
use <assemblies/coupler_comparison_assembly.scad>
use <components/_lib/reference_grid.scad>
use <components/_lib/reference_box.scad>
use <components/hub75_panel.scad>

/* [View] */
view_mode = "assembly"; // [assembly, exploded, panels, single_panel, couplers, tubes, middle_panel_coupler, horizontal_edge_panel_coupler, rear_fit_section, corner_edge_panel_coupler_left, corner_edge_panel_coupler_right, couplers_side_by_side, couplers_stacked]

/* [Coupler profile] */
coupler_design_profile = "medium"; // [small,medium,large,custom]

/* [Custom coupler dimensions] */
// These seven fields are the complete editable custom profile.
profile_size = 80;
wall_thickness = 4;
guide_height = 6;
base_thickness = 3;
corner_radius = 8;
edge_radius = 4;
tube_clip_offset = 25;

// Pass the visible Customizer values into all project components and assemblies.
$coupler_design_profile = coupler_design_profile;
$coupler_custom_profile_size = profile_size;
$coupler_custom_wall_thickness = wall_thickness;
$coupler_custom_guide_height = guide_height;
$coupler_custom_base_thickness = base_thickness;
$coupler_custom_corner_radius = corner_radius;
$coupler_custom_edge_radius = edge_radius;
$coupler_custom_tube_clip_offset = tube_clip_offset;

/* [Visibility] */
show_panels = true;
show_couplers = true;
show_stiffening_tubes = true;
show_orientation = false;
show_panel_numbers = false;
show_in_out_labels = false;
show_project_envelope = false;

/* [Panel settings] */
// Reference grid is currently supported by the single_panel inspection view.
// The geometry itself remains generic so other inspection views can reuse it later.
show_reference_grid = true;
reference_grid_spacing = 10; // [5:5:20]
reference_grid_half_step = true;

/* [Exploded view] */
exploded_distance = 40; // [10:5:80]

if(view_mode == "assembly")
    display_assembly(
        panels_visible=show_panels,
        couplers_visible=show_couplers,
        stiffening_tubes_visible=show_stiffening_tubes,
        orientation_visible=show_orientation,
        panel_numbers_visible=show_panel_numbers,
        in_out_labels_visible=show_in_out_labels
    );

if(view_mode == "exploded")
    display_assembly(
        panels_visible=show_panels,
        couplers_visible=show_couplers,
        stiffening_tubes_visible=show_stiffening_tubes,
        orientation_visible=show_orientation,
        panel_numbers_visible=show_panel_numbers,
        in_out_labels_visible=show_in_out_labels,
        explode_distance=exploded_distance
    );

if(view_mode == "panels")
    panels_assembly(
        orientation_visible=show_orientation,
        panel_numbers_visible=show_panel_numbers,
        in_out_labels_visible=show_in_out_labels
    );

// Generic reference-grid geometry lives in components/_lib/reference_grid.scad.
// Each supported view supplies its own extents and plane position.

// Single physical HUB75 panel, centred at the local component origin.
// This view is intended for tuning panel details such as the IDC connector.
if(view_mode == "single_panel") {
    project_hub75_panel(
        orientation_visible=show_orientation,
        show_connectors=true
    );

    if(show_reference_grid)
        reference_grid_xz(
            width=hub75_panel_width(),
            height=hub75_panel_height(),
            y=hub75_panel_mounting_plane_y() + 3.6,
            major=reference_grid_spacing,
            show_half=reference_grid_half_step
        );
}

if(view_mode == "couplers")
    couplers_assembly();

if(view_mode == "tubes")
    tubes_assembly();

if(view_mode == "middle_panel_coupler")
    project_middle_panel_coupler();

if(view_mode == "rear_fit_section")
    rear_fit_section(
        depth=5.0,
        show_panel_numbers=show_panel_numbers,
        show_io_labels=show_in_out_labels
    );


// Top and bottom are the same printable component.  The assembly mirrors/
// orients it as required, so one canonical component view is sufficient.
if(view_mode == "horizontal_edge_panel_coupler")
    project_horizontal_edge_panel_coupler(direction="top", screw_row_z=panel_hole_z_top());

if(view_mode == "corner_edge_panel_coupler_left")
    project_corner_edge_panel_coupler(side="left", direction="top", screw_row_z=panel_hole_z_top());

if(view_mode == "corner_edge_panel_coupler_right")
    project_corner_edge_panel_coupler(side="right", direction="top", screw_row_z=panel_hole_z_top());

if(view_mode == "couplers_side_by_side")
    coupler_comparison_side_by_side(
        show_grid=show_reference_grid,
        grid_major=reference_grid_spacing,
        grid_half_step=reference_grid_half_step
    );

if(view_mode == "couplers_stacked")
    coupler_comparison_stacked(
        show_grid=show_reference_grid,
        grid_major=reference_grid_spacing,
        grid_half_step=reference_grid_half_step
    );


// Optional project-level dimensional check. The 840 x 360 rectangle is
// centred on X=0 / Z=0. Four Y-direction corner lines make the current design
// depth explicit from the panel front face to the Y=0 rear mounting plane.
if(show_project_envelope)
    reference_box_wireframe(
        x_min=display_envelope_x_min(),
        x_max=display_envelope_x_max(),
        y_min=display_envelope_y_min(),
        y_max=display_envelope_y_max(),
        z_min=display_envelope_z_min(),
        z_max=display_envelope_z_max(),
        line_thickness=0.6
    );

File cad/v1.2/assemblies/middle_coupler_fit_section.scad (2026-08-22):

// HUB75 display frame - V1.2 middle coupler fit section
//
// Two real HUB75 panel components plus the real middle seam coupler.
// Everything behind a plane 5 mm into the rear of the panels is removed,
// leaving a true exposed 3D section through the rib/coupler interface.

include <../config/project_config.scad>
use <panels_assembly.scad>
use <couplers_assembly.scad>

/* [Section] */
fit_section_depth = 5.0;
fit_section_crop_width = 145.0;
fit_section_crop_height = 115.0;

module left_fit_panel() {
    translate([
        panel_center_x(0) - seam_x(0),
        panel_front_y,
        panel_center_z() - panel_hole_z[1]
    ])
        project_hub75_panel(
            orientation_visible=false,
            show_connectors=false
        );
}

module right_fit_panel() {
    translate([
        panel_center_x(1) - seam_x(0),
        panel_front_y,
        panel_center_z() - panel_hole_z[1]
    ])
        rotate([0,180,0])
            project_hub75_panel(
                orientation_visible=false,
                show_connectors=false
            );
}

module section_keep_volume(depth, crop_width, crop_height) {
    section_y = coupler_y - depth;

    // Keep the front side up to the section plane and crop around the local
    // middle-coupler area. The cut face itself lies at Y=section_y.
    translate([
        -crop_width/2,
        -1.0,
        -crop_height/2
    ])
        cube([
            crop_width,
            section_y + 1.0,
            crop_height
        ]);
}

module middle_coupler_fit_section(
    depth=fit_section_depth,
    crop_width=fit_section_crop_width,
    crop_height=fit_section_crop_height
) {
    color([0.68, 0.68, 0.68, 1])
        intersection() {
            union() {
                left_fit_panel();
                right_fit_panel();
            }
            section_keep_volume(depth, crop_width, crop_height);
        }

    color(color_middle_coupler)
        intersection() {
            translate([0, coupler_y, 0])
                project_middle_coupler();
            section_keep_volume(depth, crop_width, crop_height);
        }
}

middle_coupler_fit_section();

$vpt = [0, coupler_y-fit_section_depth, 0];
$vpr = [72, 0, 180];
$vpd = 190;

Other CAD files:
v1.2/out/reference/hub75-display-frame-middle-reference.dxf
v1.2/out/reference/hub75-display-frame-horizontal-edge-reference.dxf
v1.2/out/reference/hub75-display-frame-corner-right-reference.dxf
v1.2/out/reference/hub75-display-frame-corner-left-reference.dxf
v1.2/out/reference/hub75-display-frame-panel-reference.dxf
v1.2/out/stl/hub75-display-frame-corner-edge-panel-coupler-right-medium.stl
v1.2/out/stl/hub75-display-frame-corner-edge-panel-coupler-right-small.stl
v1.2/out/stl/hub75-display-frame-corner-edge-panel-coupler-left-large.stl
cad/v1.2/components/middle_seam_coupler.scad
cad/v1.2/components/_lib/coupler_profile.scad
cad/v1.2/components/corner_edge_panel_coupler.scad
cad/v1.2/components/horizontal_edge_panel_coupler.scad
cad/v1.2/components/middle_panel_coupler.scad
cad/v1.2/exports/corner_edge_panel_coupler_left.scad
cad/v1.2/exports/corner_edge_panel_coupler_right.scad
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

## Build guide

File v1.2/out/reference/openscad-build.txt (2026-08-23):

Generated with: OpenSCAD version 2026.08.22
Requested version: latest
Resolved snapshot: 2026.08.22
Latest refresh policy: 30 day(s)

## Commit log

2026-08-18 initial version
    [aluminium_extrusion.scad, bracket_bolts_assembly.scad, corner_bracket.scad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]
2026-08-19 added first iteration of version 1.1
    [aluminium_stiffening_tube.scad, display_assembly.scad, frame_module.scad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]
2026-08-19 added some more views
    [exploded_rear.scad, exploded_rear_angled.scad, front_angled.scad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]
2026-08-19 update v1.0 to support rendering
    [exploded_rear.scad, exploded_rear_angled.scad, front.scad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]
2026-08-20 added missing scad file
    [display_assembly.scad]
2026-08-21 added first v1.2 revision
    [aluminium_tube.scad, couplers_assembly.scad, display_assembly.scad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]
2026-08-21 added v1.2 panel render
    [panel.scad, panel_angled.scad]
2026-08-21 changed cemera distance for render
    [panel.scad, panel_angled.scad]
2026-08-21 changed render views
    [exploded_rear.scad, exploded_rear_angled.scad, front.scad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]
2026-08-21 small changes in render files
    [exploded_rear_angled.scad, front_angled.scad, rear.scad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]
2026-08-22 new hub75 model
    [hub75_panel.scad, panel.scad, panel_angled.scad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]
2026-08-22 added new display coupler
    [couplers_assembly.scad, exploded_rear.scad, exploded_rear_angled.scad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]
2026-08-22 Update OpenSCAD generated outputs
    [hub75-display-frame-middle-seam-coupler.stl]
2026-08-22 added fit rendering
    [main.scad, panels_assembly.scad, project_config.scad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]
2026-08-22 update new edge and corner pannel coupler
    [corner_edge_panel_coupler.scad, corner_edge_panel_coupler_left.scad, corner_edge_panel_coupler_right.scad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]
2026-08-22 removed two image files
    [hub75-display-frame-middle-seam-coupler.stl]
2026-08-23 made the parts smaller en more generic
    [corner_edge_panel_coupler.scad, coupler_profile.scad, couplers_assembly.scad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]
2026-08-23 added cutout for small 3mm pin on hub75 panels
    [corner_edge_panel_coupler.scad, couplers_assembly.scad, horizontal_edge_panel_coupler.scad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]
2026-08-23 small tweaks, give it a little bit of an industrial look, not all functional
    [corner_edge_panel_coupler.scad, coupler_profile.scad, horizontal_edge_panel_coupler.scad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]
2026-08-23 small render fix
    [coupler_profile.scad, couplers_assembly.scad]
2026-08-23 collection of small tweaks
    [corner_edge_panel_coupler.scad, horizontal_edge_panel_coupler.scad, hub75_panel.scad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]
2026-08-23 split components into reusable and project components, build semetric round zero.
    [aluminium_tube.scad, corner_edge_panel_coupler.scad, corner_edge_panel_coupler_left.scad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]
2026-08-23 fix in exports
    [corner_edge_panel_coupler_left.scad, corner_edge_panel_coupler_right.scad, horizontal_edge_panel_coupler.scad]
2026-08-23 a lot of tweaks
    [corner_edge_panel_coupler.scad, coupler_dimensions.scad, coupler_profile.scad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]
2026-08-23 add missing assembly
    [coupler_comparison_assembly.scad]
2026-08-23 beter alignment of the decorative holes
    [corner_edge_panel_coupler.scad, coupler_comparison_assembly.scad, coupler_dimensions.scad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]
2026-08-24 update with small, medium and large connectors
    [corner_edge_panel_coupler_left_large.scad, corner_edge_panel_coupler_left_medium.scad, corner_edge_panel_coupler_left_small.scad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]
2026-08-25 restructure of archive
    [aluminium_extrusion.scad, aluminium_stiffening_tube.scad, aluminium_tube.scad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]
2026-08-29 #1: improvements in layout and ribs
    [corner_edge_panel_coupler.scad, coupler_dimensions.scad, coupler_profile.scad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]
2026-08-29 #1: restored rib for middle and horizontal coupler
    [coupler_dimensions.scad, horizontal_edge_panel_coupler.scad, hub75_panel.scad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]
2026-08-29 #1: add extra renderes to check fit for horizonal edge en middle connector
    [coupler_fit_cross_sections.scad, horizontal_edge_fit_cross_section.scad, middle_panel_fit_cross_section.scad]
2026-08-29 @1: changed code for diagnostic renders for horizontal edge and middle connector
    [coupler_fit_cross_sections.scad, horizontal_edge_fit_cross_section.scad, middle_panel_fit_cross_section.scad]
2026-08-29 #1: improvements in diagnostic renders
    [hub75_panel.scad, panels_assembly.scad, rear_fit_section.scad]
2026-08-29 #1: new fixes
    [coupler_fit_cross_sections.scad, horizontal_edge_fit_cross_section.scad, middle_panel_fit_cross_section.scad]
2026-08-29 #1: improve rib design
    [horizontal_edge_panel_coupler.scad, middle_panel_coupler.scad]
2026-08-30 #1: improvements in fitting of couplers
    [corner_edge_panel_coupler.scad, corner_left_reference.scad, corner_right_reference.scad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]
2026-08-30 removed some old STL files
    [hub75-display-frame-corner-edge-panel-coupler-left.stl, hub75-display-frame-corner-edge-panel-coupler-right.stl, hub75-display-frame-horizontal-edge-panel-coup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]
2026-08-30 #2: add new configuration parameters for connectors
    [corner_edge_panel_coupler.scad, coupler_comparison_assembly.scad, horizontal_edge_panel_coupler.scad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]
2026-08-30 #2: improvements in coupler size, rounding etc
    [corner_edge_panel_coupler.scad, horizontal_edge_panel_coupler.scad, middle_panel_coupler.scad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]
2026-08-30 #2: some improvements
    [corner_edge_panel_coupler.scad, horizontal_edge_panel_coupler.scad, middle_panel_coupler.scad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]
2026-08-30 #2: some fixes, especially for plate size for small couplers
    [corner_edge_panel_coupler.scad, coupler_comparison_assembly.scad, main.scad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]
2026-08-30 #2: update render of angled views (the where upside down), restructure coupler en dependency of hub75 panel model
    [corner_edge_panel_coupler.scad, coupler_dimensions.scad, exploded_rear_angled.scad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]
2026-08-30 #2: fixes in rouding of guides for couplers
    [corner_edge_panel_coupler.scad, coupler_dimensions.scad, coupler_profile.scad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]
2026-08-30 #2: fixes
    [coupler_dimensions.scad, coupler_profile.scad, horizontal_edge_panel_coupler.scad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]
